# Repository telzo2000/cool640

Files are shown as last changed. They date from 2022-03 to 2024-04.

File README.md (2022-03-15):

# cool640

<br>

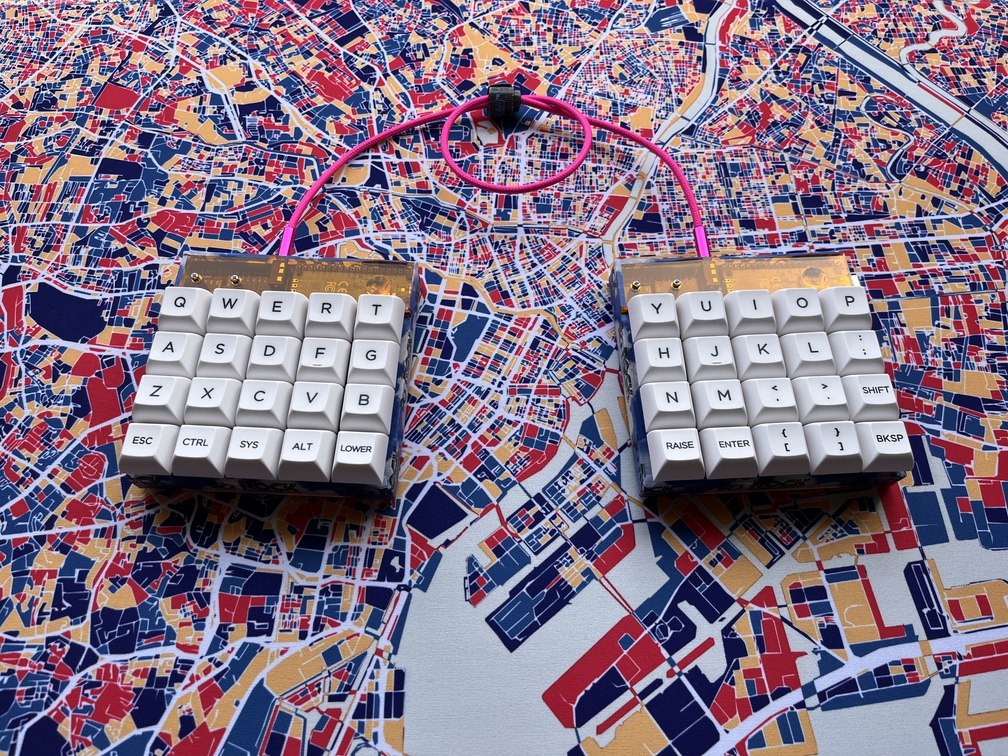
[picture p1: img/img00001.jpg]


## What is cool640？

cool640 is 4X5 macro pad keyboard.
<br>
If you align the two, you will have a split keyboard.
<br><br>
cool640は4X5のマクロパッドキーボードです。
<br>
cool640は二つ揃えると、分割キーボードになります。
<br><br>
You can choose either pro micro or raspberry pi pico to use.
<br><br>
pro microかraspberry pi picoのどちらか一つを選んで使うことができます。

<br><br>
You can choose either choc switch or cherry mx switch to use.
<br>
Chocスイッチか CHERRY MXスイッチのどちらか一つを選んで使うことができます。

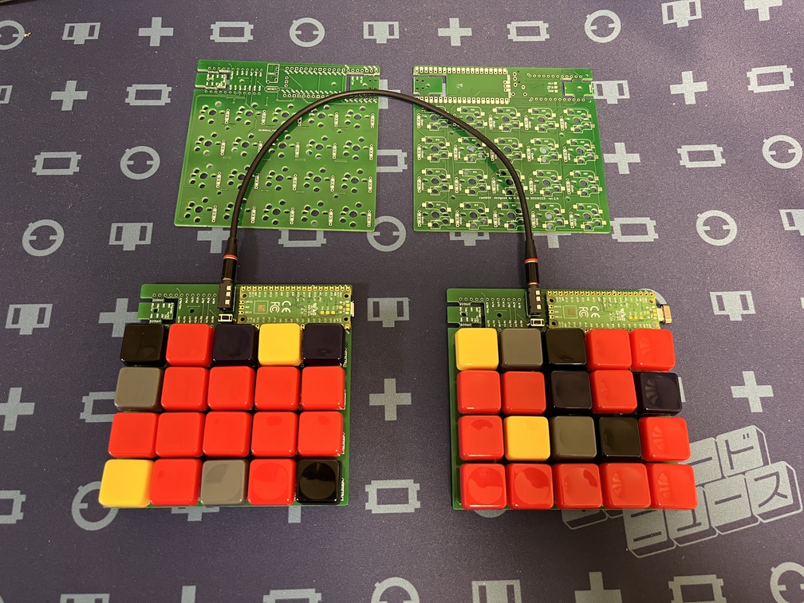
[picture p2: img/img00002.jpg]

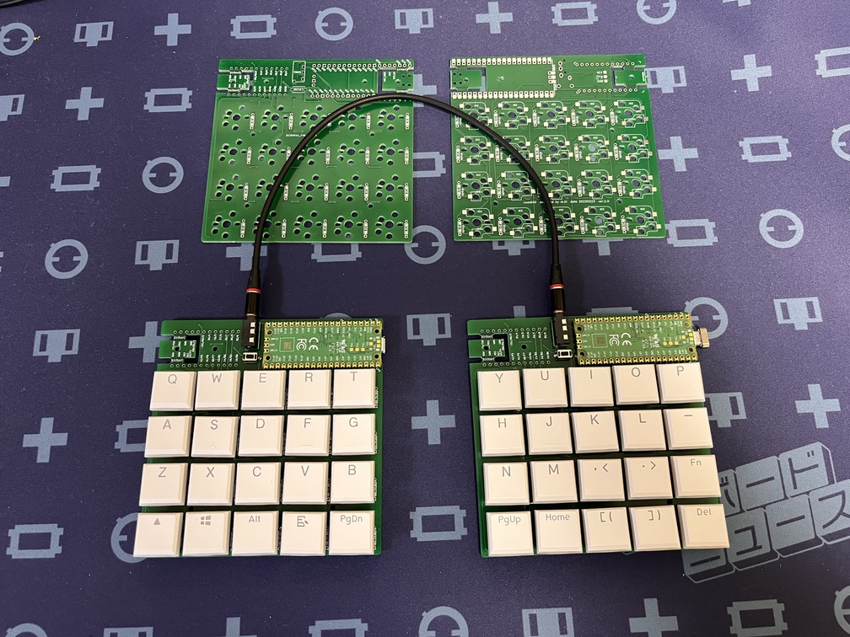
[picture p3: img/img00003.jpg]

<br>
The size of the PCB is within 100mmX100mm.
<br>
It will be distributed on booth in the future, but you can freely use the data here and place an order with the PCB manufacturer.
<br><br>
PCBのサイズは、100mmX100mm以内です。
<br>
将来、boothにて頒布しますが、ここにあるデータを自由に使い、各自がPCB製造元に発注しても構いません。
<br><br>
I do not take any responsibility for the data that you freely use.
<br>
Please use at your own risk.
<br><br>
各自が自由に使ったデータについては、私は一切の責任を負いません。
<br>
自己責任で利用してください。
<br>

## Build Guide
https://github.com/telzo2000/cool640/blob/main/buildguide_for_cool640.md

<br>

## Firmware
https://github.com/telzo2000/cool640/tree/main/firmware

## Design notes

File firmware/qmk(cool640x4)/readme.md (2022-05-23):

# cool640x2

cool640x2

*A short description of the keyboard/project*

* Keyboard Maintainer: [m.ki](https://github.com/telzo2000)
* Hardware Supported: *The PCBs, controllers supported*
* Hardware Availability: *Links to where you can find this hardware*

Make example for this keyboard (after setting up your build environment):

    make cool640x2:default

Flashing example for this keyboard:

    make cool640x2:default:flash

See the [build environment setup](https://docs.qmk.fm/#/getting_started_build_tools) and the [make instructions](https://docs.qmk.fm/#/getting_started_make_guide) for more information. Brand new to QMK? Start with our [Complete Newbs Guide](https://docs.qmk.fm/#/newbs).

## Bootloader

Enter the bootloader in 3 ways:

* **Bootmagic reset**: Hold down the key at (0,0) in the matrix (usually the top left key or Escape) and plug in the keyboard
* **Physical reset button**: Briefly press the button on the back of the PCB - some may have pads you must short instead
* **Keycode in layout**: Press the key mapped to `RESET` if it is available

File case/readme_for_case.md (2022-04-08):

The size of the acrylic board is listed at the end of the file name.
<br>
ファイル名の末尾にアクリル板のサイズが記載してあります。
<br>
The thickness of acrylic is 2mm.
<br>
アクリルの厚みは、２mmです。
<br>
<br>
ボトムプレートを自作する場合、
<br>
横が98.24mm、縦が99.47mmで設計されているので、
<br>
ほぼ、100mm四方のアクリルを使って、必要な箇所にネジ穴（直径2mm程度）を作れば、PCBからM2ネジを挿しこみ、スペーサー等を使って、ボトムプレート固定することができます。
<br>

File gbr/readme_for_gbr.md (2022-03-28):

The dimensions of the PCB will be 98mmX98mm.
<br>
If you place an order with Elecrow, you will need to change the extension.
<br>
PCBの寸法は98mmX98mmになります。
<br>
Elecrowに発注する場合は、拡張子の変更が必要となります。
<br>
elecrow用に拡張子を変更したものが、elecrowという名のリポジトリ内にあります。

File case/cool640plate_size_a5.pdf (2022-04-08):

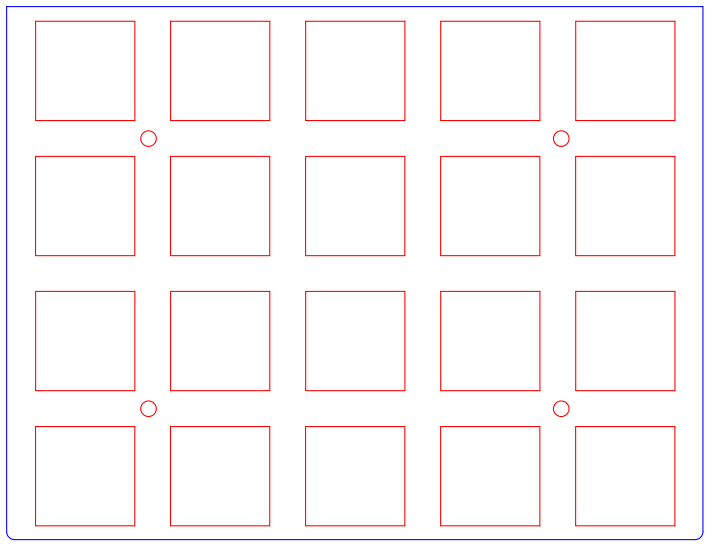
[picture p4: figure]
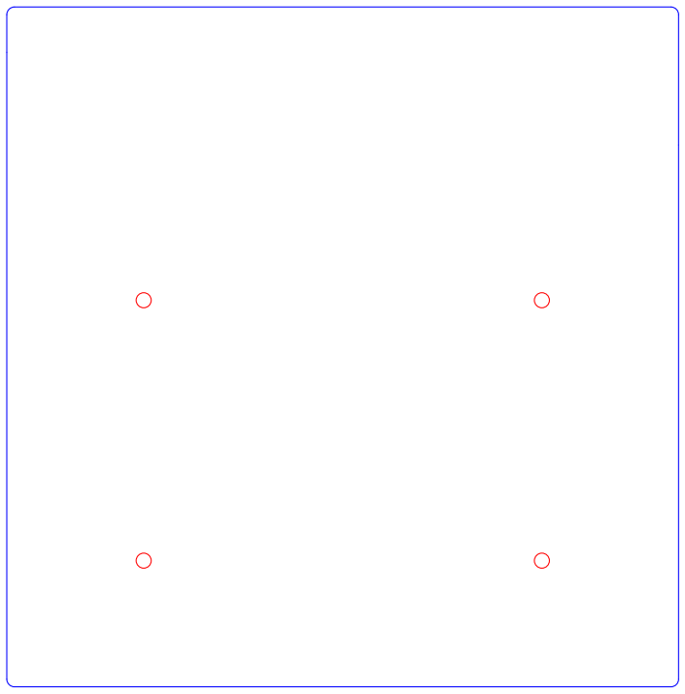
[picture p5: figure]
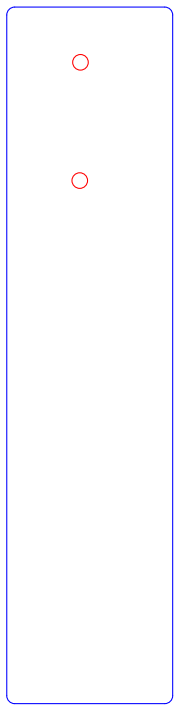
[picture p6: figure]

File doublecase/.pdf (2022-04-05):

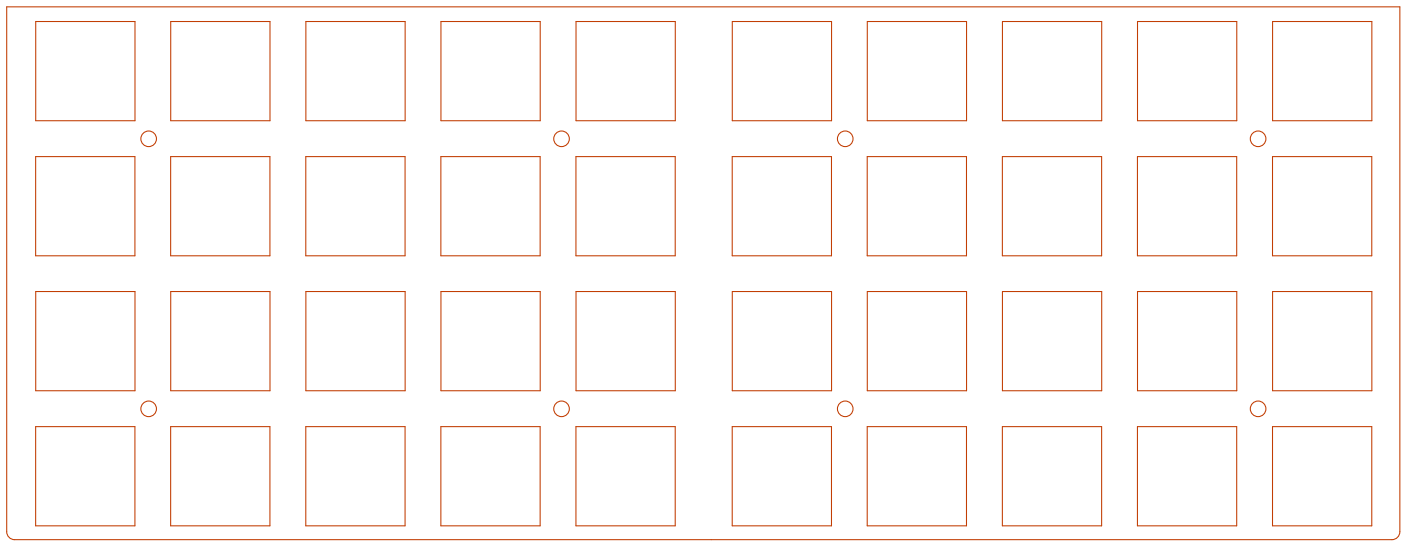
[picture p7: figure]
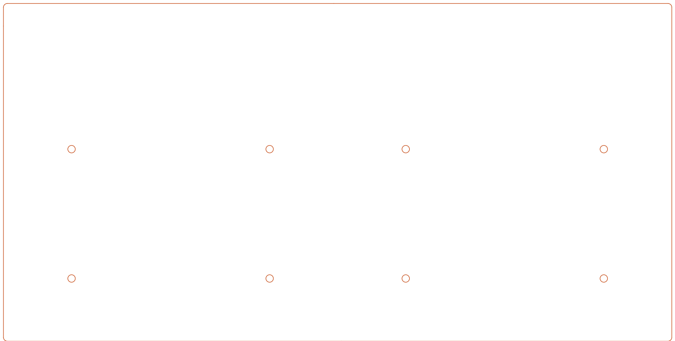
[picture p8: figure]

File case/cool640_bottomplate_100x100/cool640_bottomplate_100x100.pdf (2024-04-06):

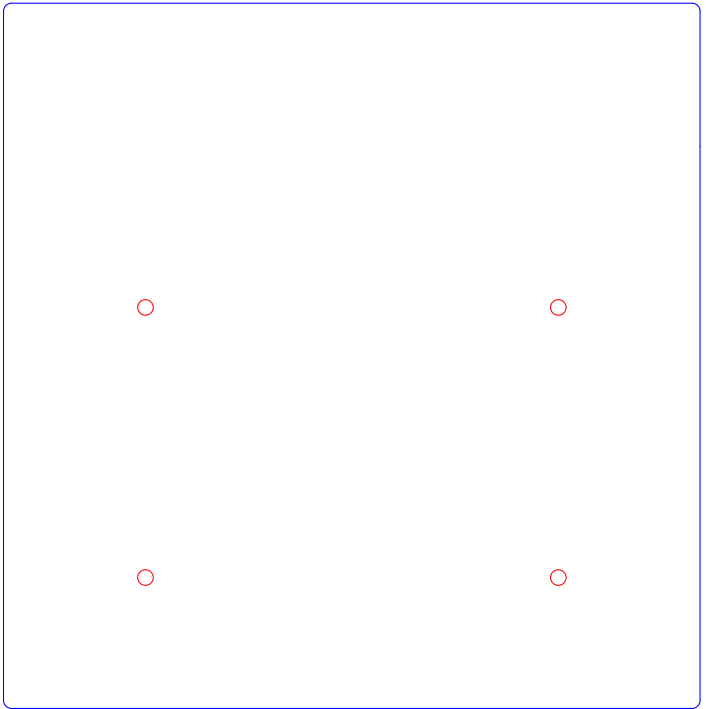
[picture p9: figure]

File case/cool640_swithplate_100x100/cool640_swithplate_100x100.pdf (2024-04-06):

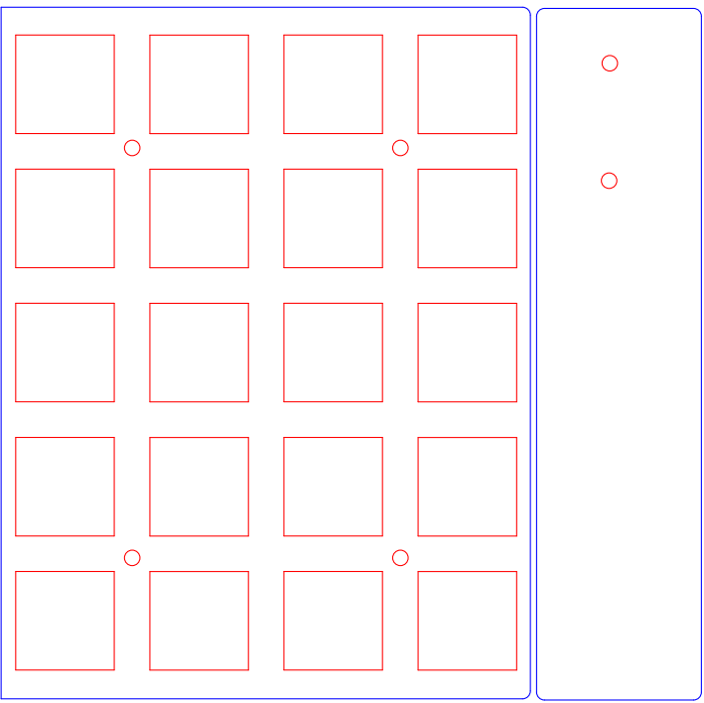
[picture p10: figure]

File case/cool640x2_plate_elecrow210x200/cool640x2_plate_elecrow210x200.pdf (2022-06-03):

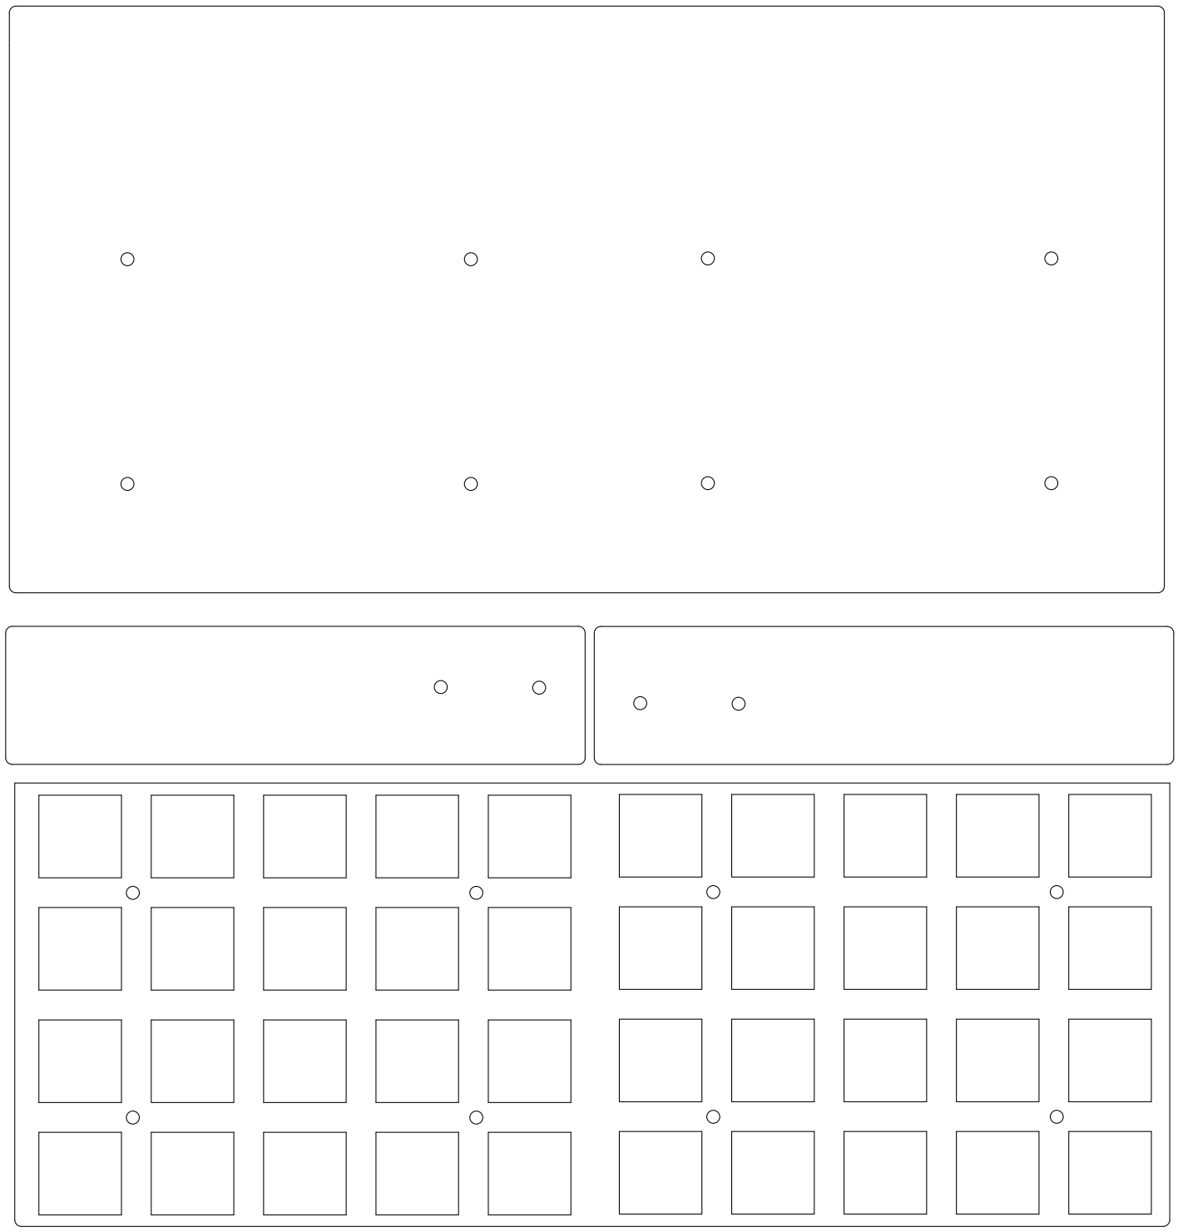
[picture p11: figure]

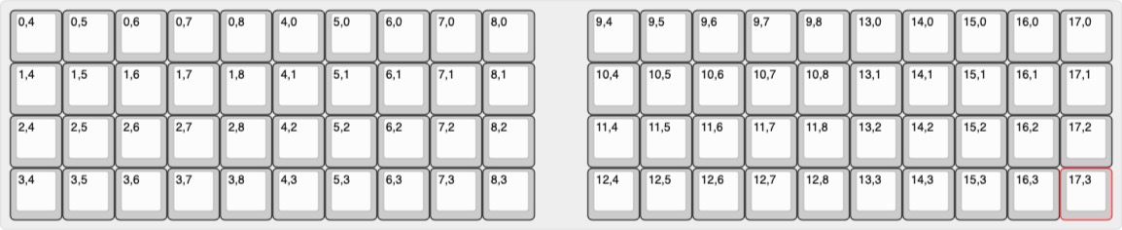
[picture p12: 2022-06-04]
cool640x4_design/cool640x4.jpg

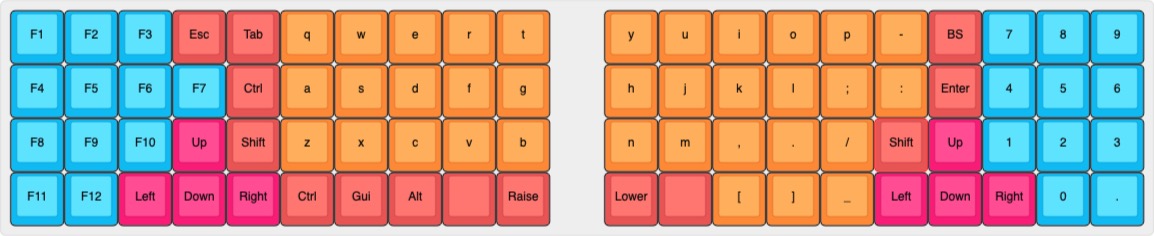
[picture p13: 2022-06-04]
cool640x4_design/cool640x4-2.jpg

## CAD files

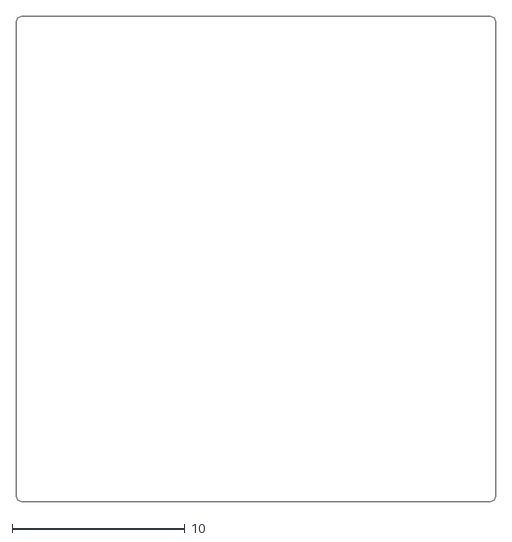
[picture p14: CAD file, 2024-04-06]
case/cool640_bottomplate_100x100/cool640_bottomplate_100x100.dxf
27.7 x 28.1

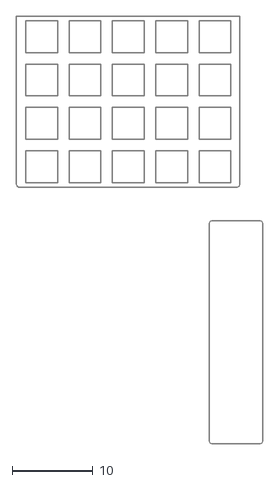
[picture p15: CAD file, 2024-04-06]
case/cool640_swithplate_100x100/cool640_swithplate_100x100.dxf
30.5 x 53.1

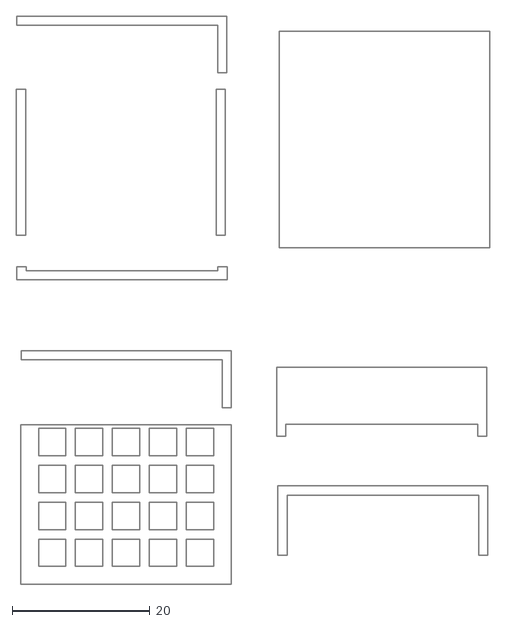
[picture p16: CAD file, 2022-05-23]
case_wide/cool640case_wide.dxf
68.9 x 82.6

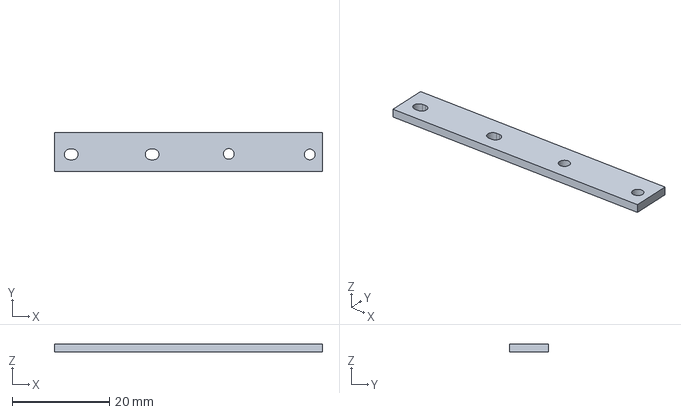
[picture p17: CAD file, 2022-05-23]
kicad_cool640/cool640gattai/cool640gattai.step
55.2 x 7.98 x 1.60 mm

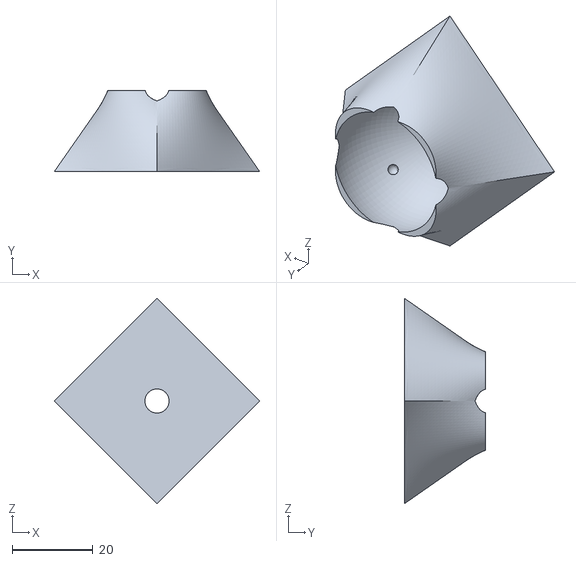
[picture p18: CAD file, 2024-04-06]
case/cool640_swithplate_100x100/trackball_case v2.stl
50.9 x 20.0 x 50.9

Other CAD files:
case/cool640_swithplate_100x100/trackball_case v1.stl

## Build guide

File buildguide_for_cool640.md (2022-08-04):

# Build guide

## Parts list

| No. | Patrs | Quantity | remarks | Suppliers | Cost |
|--|--|--|--|--|--|
|番号|名前|数|備考|調達先|参考価格（送料込）|<br>
|1|PCB|1|4X5Macro pad<br>keyboard|[elecrow](https://www.elecrow.com)<br>[JLCPCB](https://jlcpcb.com)<br>[ALLPCB](https://www.allpcb.com)|５枚で10〜20ドル|<br>
||PCB|2|40%splite keyboard|↑|↑|
|2-1|Switch Plate<br>スイッチプレート|１〜２|Macropadは１枚<br>splite keyboardは２枚|[工房Emerge+](https://www.emergeplus.jp/laser-cutting-service/contact/)<br>[遊舎工房](https://yushakobo.jp)<br>[elecrow](https://www.elecrow.com)|種類による。|
|2-2|Cover Plate<br>カバープレート|１～２|↑|↑|↑|
|2-3|Bottom Plate<br>ボトムプレート|１～２|↑|↑|↑|
|3|M2screw<br>M2ネジ|4X1〜2|4mm<br>CoverPlateで使用|DIYショップなど|10本で100円程度|
|4|M2screw<br>M2ネジ|4X1〜2|3mm|↑|↑|
|5A|M2screw<br>M2ネジ|4X1〜2|8mm<br>MXスイッチ使用時|↑|↑|
|5B|M2screw<br>M2ネジ|4X1〜2|6mm<br>chocスッチ使用時|↑|↑|
|6A|M2spacer<br>M2スペーサー|8X1〜2|3mmメス-メス<br>MXスイッチ使用時|[ヒロスギネット](https://www.hirosugi-net.co.jp/shop/c/c10/)<br>[遊舎工房](https://yushakobo.jp)|20本で800円程度|
|6B|M2spacer<br>M2スペーサー|4X1〜2|3mmメス-メス<br>chocスイッチ使用時|[ヒロスギネット](https://www.hirosugi-net.co.jp/shop/c/c10/)<br>[遊舎工房](https://yushakobo.jp)|20本で800円程度|
|7|M2spacer<br>M2スペーサー|2X1〜2|6mmメス-メス<br>CoverPlateで使用|[ヒロスギネット](https://www.hirosugi-net.co.jp/shop/c/c10/)<br>[遊舎工房](https://yushakobo.jp)|20本で800円程度|
|8|pro micro|1〜2|ピンヘッダも別途購入|[遊舎工房](https://yushakobo.jp)<br>[Talp Keyboard](https://talpkeyboard.net)<br>[Daily Craft Keyboard](https://shop.dailycraft.jp)等|価格変動中|
||Raspberry Pi Pico|1〜2|ピンヘッダも別途購入|[遊舎工房](https://yushakobo.jp)等|１個550円|
|9A|Swith socket<br>スイッチソケット|20X1〜2|cherry MX互換|[遊舎工房](https://yushakobo.jp)<br>[Talp Keyboard](https://talpkeyboard.net)<br>[Daily Craft Keyboard](https://shop.dailycraft.jp)等|10個で165円程度|
|9B|Swith socket<br>スイッチソケット|20X1〜2|choc互換|[遊舎工房](https://yushakobo.jp)<br>[Talp Keyboard](https://talpkeyboard.net)<br>[Daily Craft Keyboard](https://shop.dailycraft.jp)等|10個で165円程度|
|10|Diode<br>ダイオード|20X1〜2|リードタイプでもSMDでも可|[遊舎工房](https://yushakobo.jp)<br>[Talp Keyboard](https://talpkeyboard.net)<br>[Daily Craft Keyboard](https://shop.dailycraft.jp)等|100個で220円程度から|
|11|タクトスイッチ|1〜2|２本足のもの|[遊舎工房](https://yushakobo.jp)<br>[Talp Keyboard](https://talpkeyboard.net)<br>[Daily Craft Keyboard](https://shop.dailycraft.jp)等|１個11円程度|
|12|TRRSジャック|1〜2|MJ-4PP-9|[遊舎工房](https://yushakobo.jp)<br>[Talp Keyboard](https://talpkeyboard.net)<br>[Daily Craft Keyboard](https://shop.dailycraft.jp)等|１個55円|

この他に、TRRSケーブル、USBケーブル、キーキャップ等が必要です。

## Firmware

### 1 PRK_FIRMWARE

[Here](https://github.com/telzo2000/cool640/tree/main/firmware)

<br>
For those who are introducing PRK for the first time.
<br>
初めてのPRKを導入する方に
<br>
Only Japanese tweets.
<br>
日本語ツイートのみです。
<br>

https://twitter.com/0002ozlet/status/1512535045957111810

### 2 QMK_FIRMWARE
[Here](https://github.com/telzo2000/cool640/tree/main/firmware)

<br>

## Build 1(PCB only)

### 1 Parts check

Front side（表面）

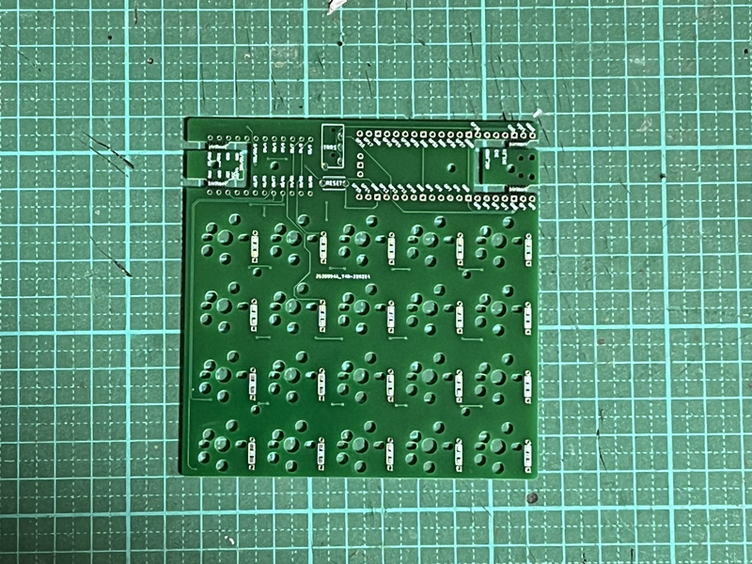
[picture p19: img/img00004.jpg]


Back side（裏面）

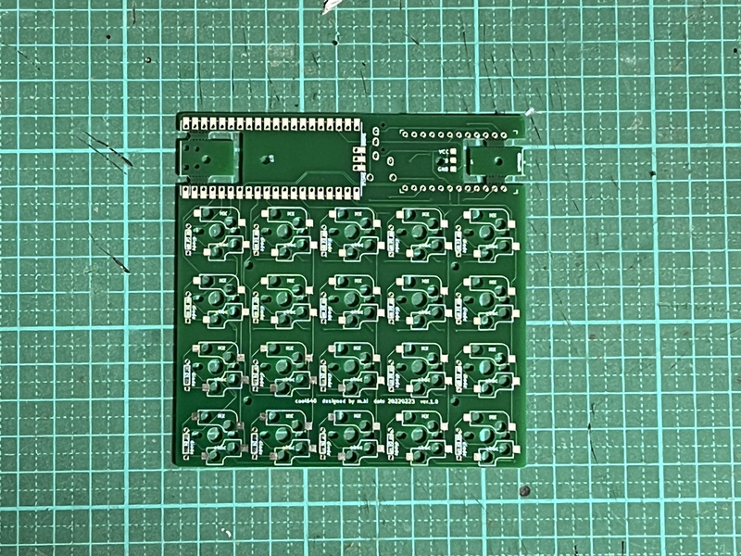
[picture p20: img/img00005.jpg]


### 2 Diode soldering

Solder the diode on the back side.
<br>
裏面にダイオードのハンダ付けをします。
<br>

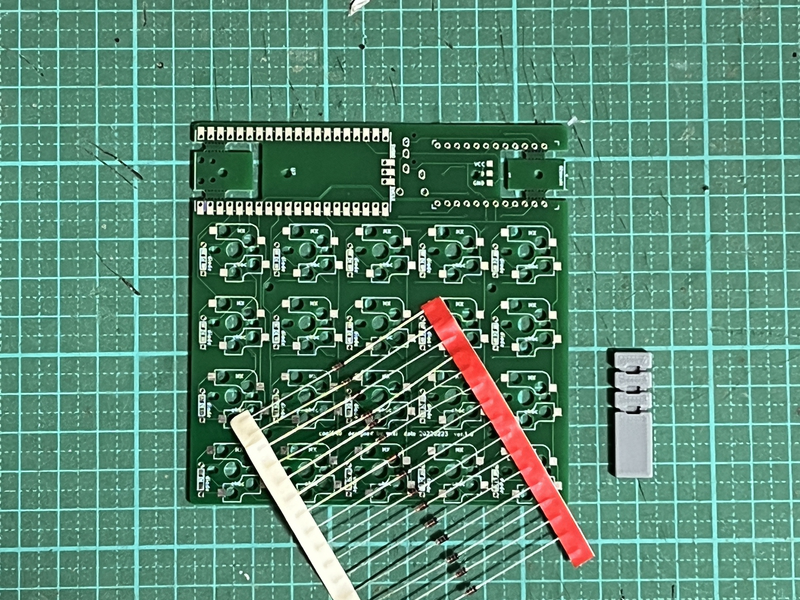
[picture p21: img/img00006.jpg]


There are lead type and SMD diodes.
<br>
ダイオードはリードタイプか、SMDがあります。
<br>
Here, we will explain the lead type soldering.
<br>
ここでは、リードタイプのハンダ付けの説明をします。
<br>
However, those who adopt the choc switch should use SMD diodes.
<br>
ただし、chocスイッチを採用する人は、SMDのダイオードを使用してください。
<br>

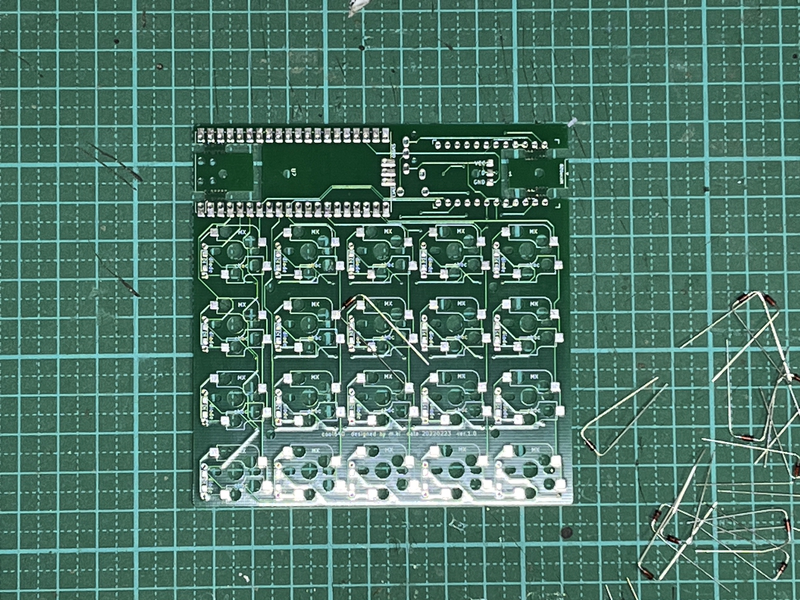
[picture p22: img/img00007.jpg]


Use a lead bender to bend the legs of the diode.
<br>
リードベンダーを使い、ダイオードの足を曲げます。
<br>

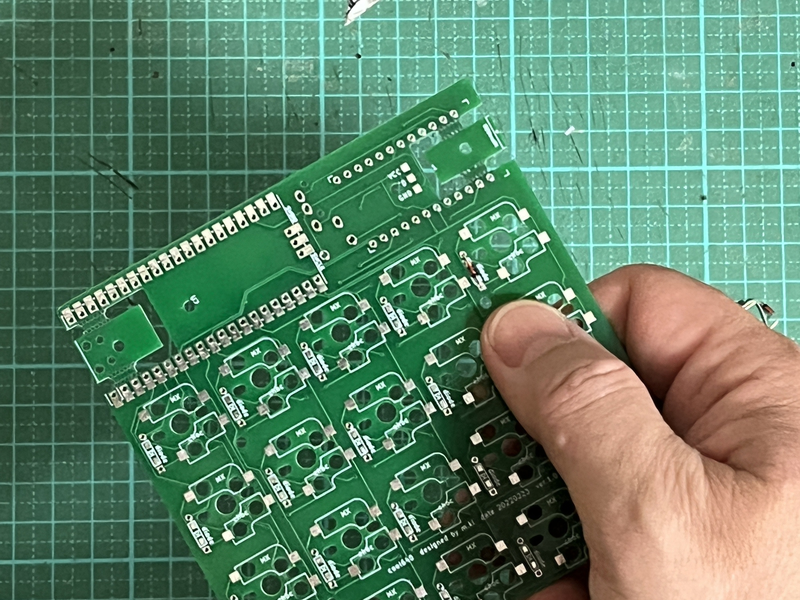
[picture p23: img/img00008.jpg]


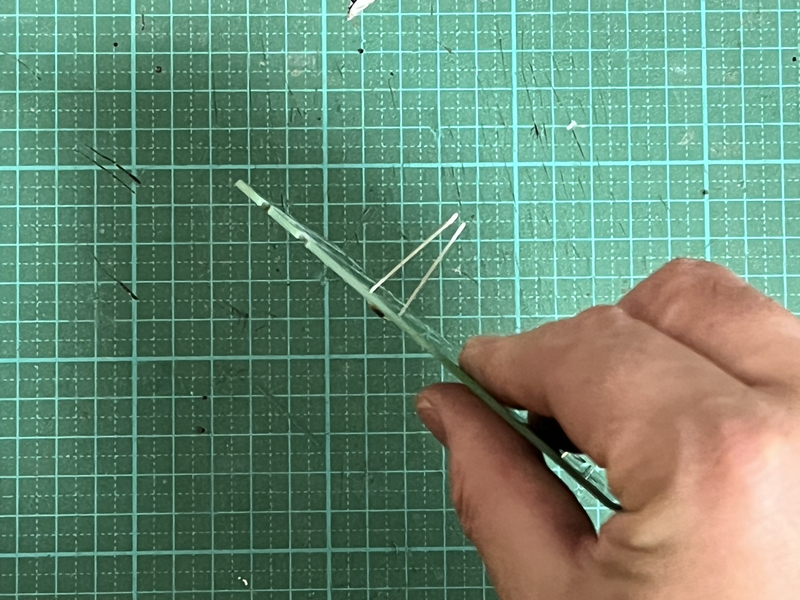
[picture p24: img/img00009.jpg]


Insert the diode into the board.
<br>
ダイオードを基板に挿しこみます。
<br>

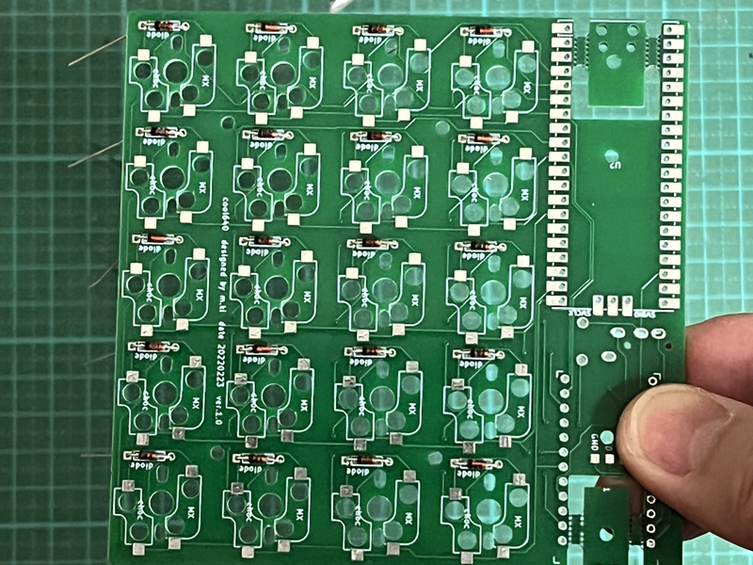
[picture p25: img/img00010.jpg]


Please refer to the image and pay attention to the orientation of the diode.
<br>
画像を参考にして、ダイオードの向きに注意してください。
<br>

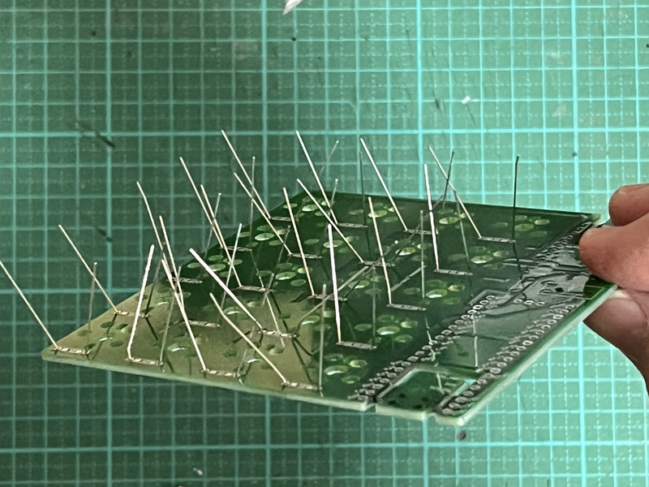
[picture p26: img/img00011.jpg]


Secure the diode with masking tape, then face up.
<br>
マスキングテープでダイオードを固定してから、表面を上にします。
<br>
Solder the protruding legs.
<br>
はみ出ている足部分に、ハンダ付けをします。
<br>
After soldering, use nippers to cut off the protruding legs.
<br>
はんだ付けが終わったら、はみ出ている足をニッパーで切り取ってください。
<br>

[８倍速　Diodeハンダ付け動画](https://youtu.be/Yaodh2-XxV4)

<br>
<br>

### 3 Soldering switch sockets

Solder the switch sockets on the back side.
<br>
裏面にスイッチソケットのハンダ付けをします。
<br>
cool640 is compatible with both choc and cherry MX switches.
<br>
cool640はchocスイッチとcherryMXスイッチの両方に対応しています。
<br>
Both can be installed.
<br>
両方を取り付けることが可能です。
<br>
Here, solder the cherryMX switch.
<br>
ここでは、cherryMXスイッチのハンダ付けを行います。
<br>
Place the switch socket so that the letters MX are hidden.
<br>
MXという文字が隠れるように、スイッチソケットを乗せてください。
<br>
That is the correct switch socket orientation.
<br>
それが正しいスイッチソケットの向きになります。
<br>
When using a choc switch, place the switch socket so that the letters choc are hidden.
<br>
chocスイッチの時は、chocという文字が隠れるように、スイッチソケットを乗せてください。
<br>

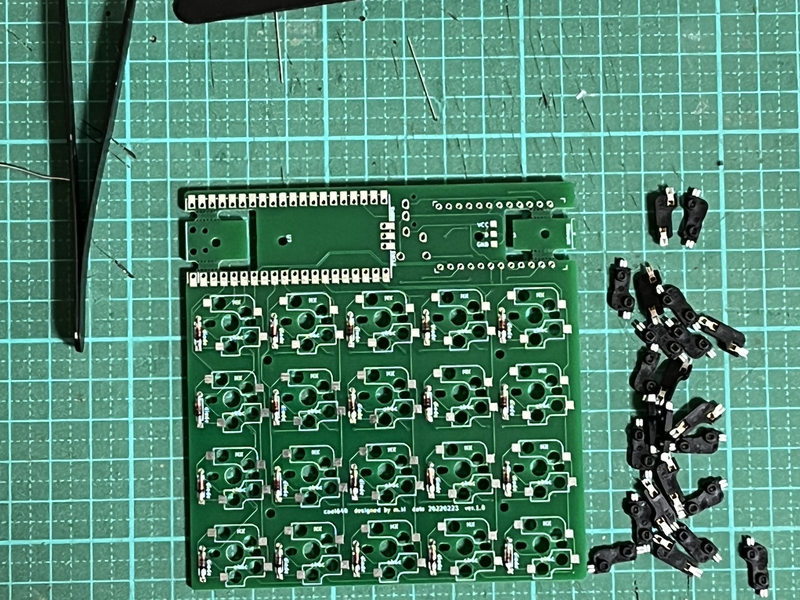
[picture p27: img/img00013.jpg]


Apply solder to both pads.
<br>
両方のパッドにハンダを盛ります。
<br>
Place the switch socket and fix it with a warm soldering iron while melting the solder.
<br>
スイッチソケットを乗せて、温めたハンダゴテで、ハンダを溶かしながら、固定します。
<br>
You can make it easier by working while holding it with tweezers.
<br>
ピンセットで押さえながら、作業をすると楽にできます。
<br>

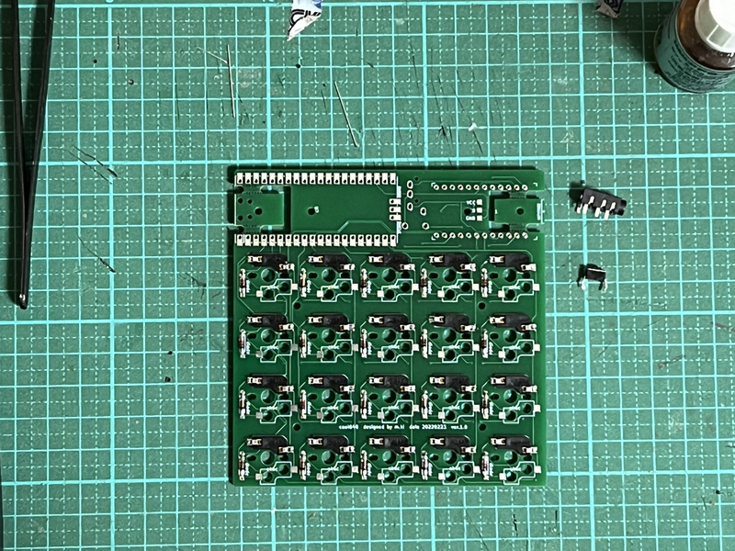
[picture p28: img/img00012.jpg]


[８倍速　Switch socketハンダ付け動画](https://youtu.be/E__mHvmIXQo)

<br><br>

### 4 Soldering reset switch & TRRS jack 

Insert the reset switch on the surface.
<br>
表面にリセットスイッチを挿しこみます。
<br>
Solder the legs of the reset switch from the back.
<br>
裏面からリセットスイッチの足をハンダ付けします。
<br>
Solder the TRRS jack in the same way near the reset switch.
<br>
TRRSジャックは、リセットスイッチの近くに同じようにハンダ付けします。

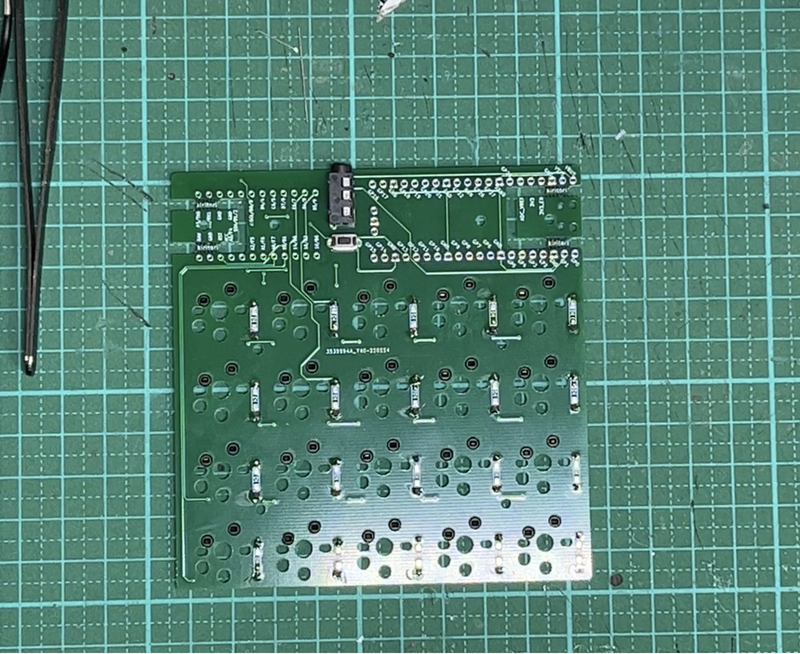
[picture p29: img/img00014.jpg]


[８倍速　Reset switch,TRRS jackハンダ付け動画](https://youtu.be/3gEbExaOAv4)

<br><br>

### 5　Choice of Pro micro or Raspberry Pi Pico

You can run cool640 in either Pro micro or Raspberry Pi Pico.
<br>
cool640をpro microかラズパイピコのどちらか一方で動作させることができます。
<br>
＜case 1＞
<br>
When you choose Pro micro, place it on the left side of the TRRS jack.
<br>
pro microを選んだ時、TRRSジャックの左側にpro microを取り付けてください。
<br>

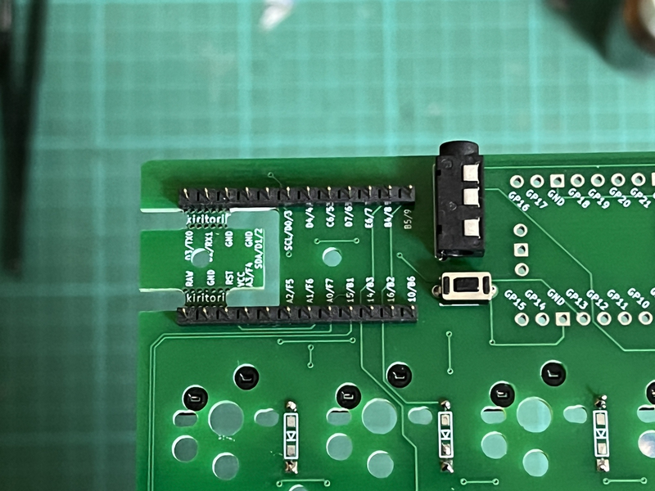
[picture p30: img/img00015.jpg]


Use the conthrough to fix the pro micro with the side with the parts facing down.
<br>
pro microの部品のある面を下向きに、コンスルーを使い、固定してください。
<br>

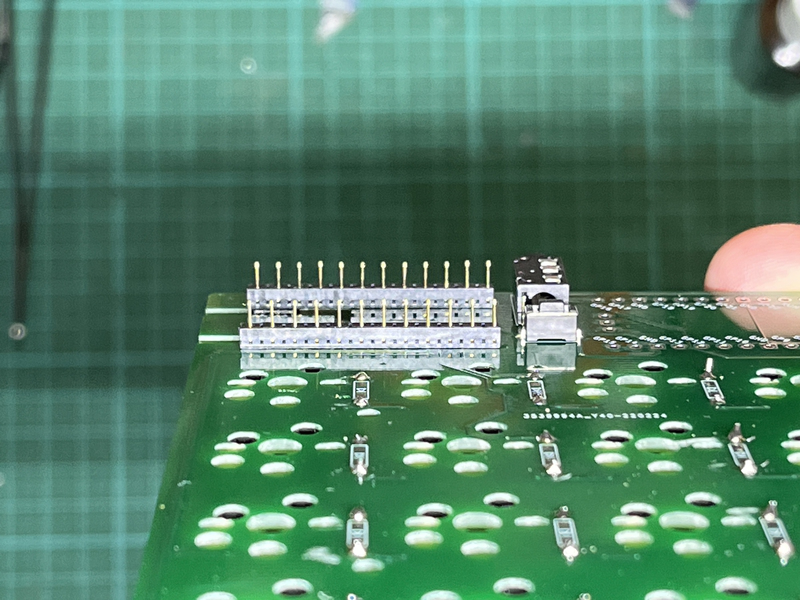
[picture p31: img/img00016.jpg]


Pay attention to the orientation of the conthrough.
<br>
コンスルーの向きに注意してください。
<br>

If the USB port touches the PCB, cut off the part on the left side of the PCB.
<br>
もし、USB端子がPCBに接触するならば、PCBの左側の一部を切りとってください。
<br>

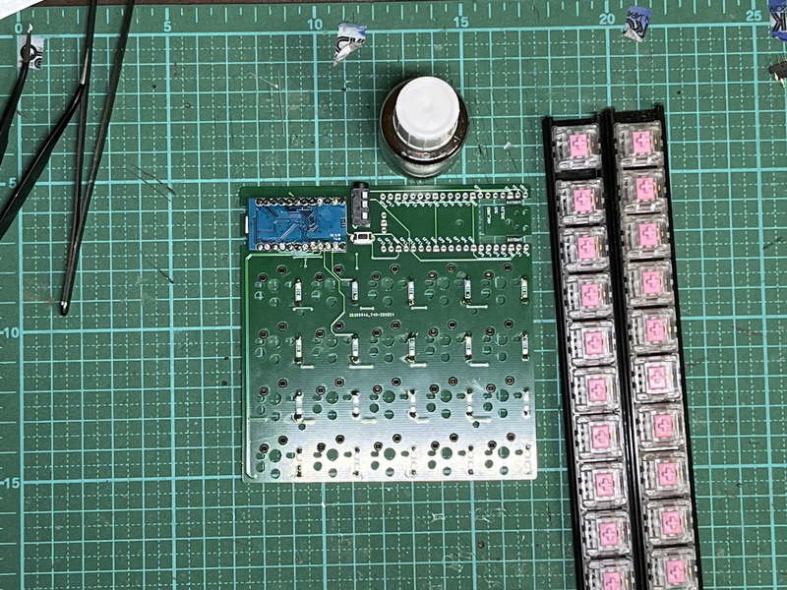
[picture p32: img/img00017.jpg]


＜case 2＞
<br>
When you choose Raspberry Pi Pico, place it on the right side of the TRRS jack.
<br>
ラズパイピコを選んだ時、TRRSジャックの右側にラズパイピコを取り付けてください。

Use the conthrough to fix the Raspberry Pi Pico with the side with the parts facing down.
<br>
ラズパイピコの部品のある面を下向きに、コンスルーを使い、固定してください。
<br>

Pay attention to the orientation of the conthrough.
<br>
コンスルーの向きに注意してください。
<br>

If the USB port touches the PCB, cut off the part on the right side of the PCB.
<br>
もし、USB端子がPCBに接触するならば、PCBの右側の一部を切りとってください。
<br>

<br>

### 6　Test

Please write the firmware and check the operation.
<br>
ファームウェアを書き込んで、動作確認をしてください。
<br>

Install a switch or measure continuity with tweezers, etc.
<br>
スイッチを取り付けるか、ピンセット等で導通をはかるかを行います。
<br>

### PRK_FIRMWARE

[Here](https://github.com/telzo2000/cool640/tree/main/firmware)

<br>

### QMK_FIRMWARE
[Here](https://github.com/telzo2000/cool640/tree/main/firmware)

<br>
<br>

### 7 Installation of key switch

Attach your favorite key switch.
<br>
好きなキースイッチを取り付けてください。
<br>

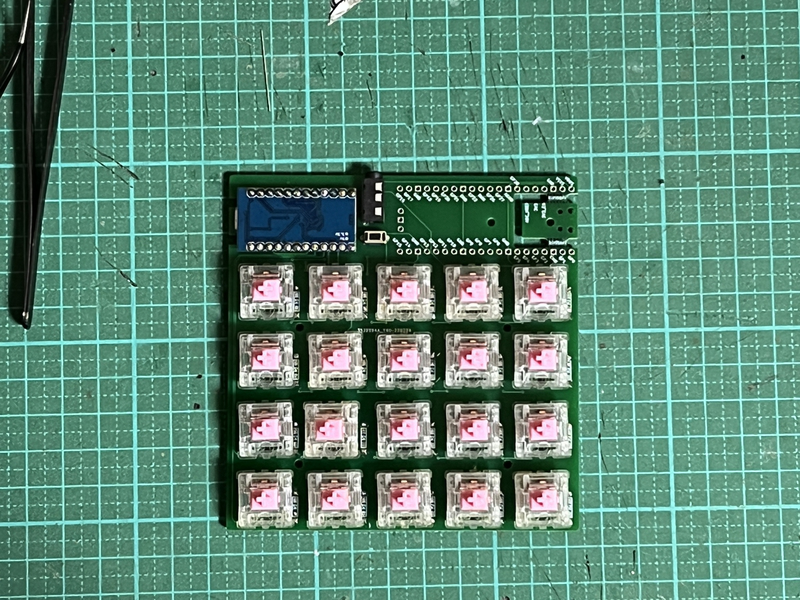
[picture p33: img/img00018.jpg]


<br>
<br>

### 8 Installation of key cap

Attach your favorite key cap.
<br>
好きなキーキャップを取り付けてください。
<br>

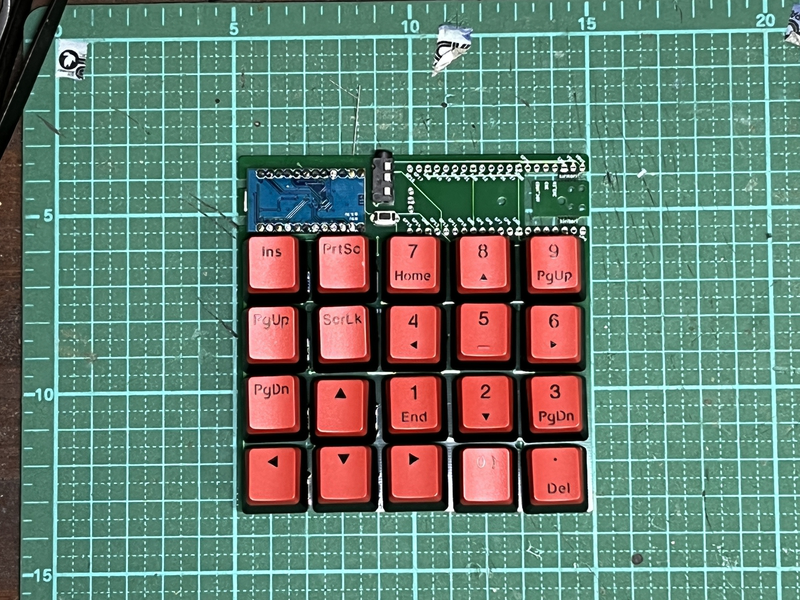
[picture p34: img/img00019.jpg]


<br>
If you like, attach a rubber cushion to the back and you're done.
<br>
お好みで裏面にラバークッションを取り付けたら、完成です。
<br>
<br>
<br>

## Build 2(Acrylic sandwich mount case)

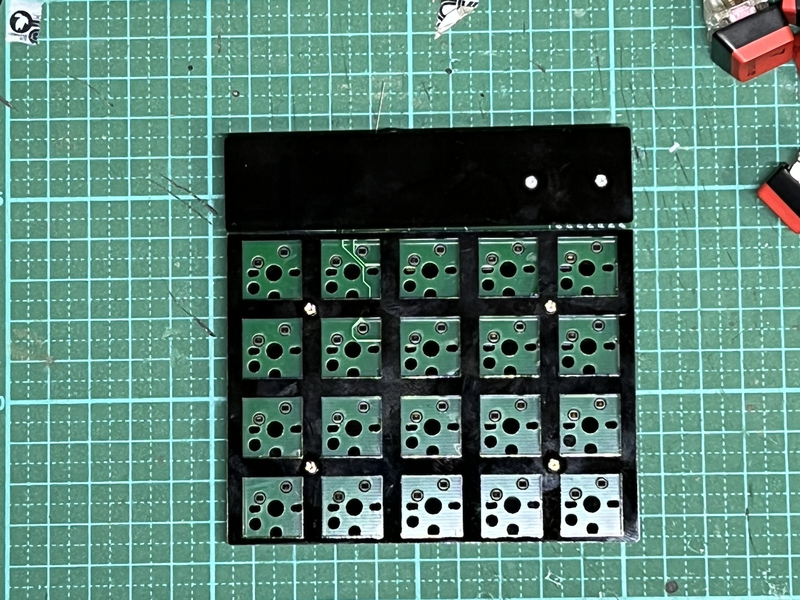
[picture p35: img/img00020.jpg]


After 1 ~ 6 of build1, please do the next step.
<br>
build1の1~6の後、次の工程をしてください。
<br>

### 1 Installation of cover plate

Prepare a cover plate, M2 spacer 6mm（x２）, and M2 screw 3mm（x４）.
<br>
カバープレート、M2スペーサー6mm（２個）、M2ネジ3mm（４本）を用意します。
<br>
Screw the spacer to the cover plate in the same orientation.
<br>
カバープレートに同じ向きで、スペーサーをネジで固定します。
<br>
Then use the remaining screws to attach the cover plate to the PCB.
<br>
次に、残りのネジを使い、カバープレートをPCBに取り付けます。
<br>
There is an orientation of the cover plate, so it is good to check it once before starting work.
<br>
カバープレートの向きがあり、作業前に一度、重ねて確認すると良いです。
<br>
<br>

### 2-1 Installation of switch plate（choc switch）

Prepare a switch plate, M2 spacer 3 mm（x４）, and M2 screw 6 mm（x４）.
<br>
スイッチプレート、M2スペーサー３mm（４本）、M2ネジ６mm（４本）を用意します。
<br>
Fix the screws in 4 places.
<br>
ネジを４箇所、固定します。
<br>
Insert the screws in the order of the switch plate and the PCB, and fix them with spacers on the back of the PCB.
<br>
ネジはスイッチプレート、PCBの順でさしこみ、PCBの裏面でスペーサーで固定します。
<br>

<br>

### 2-2 Installation of switch plate（cherry MX switch）

Prepare a switch plate, M2 spacer 3 mm（x８）, and M2 screw 8 mm（x４）.
<br>
スイッチプレート、M2スペーサー３mm（８本）、M2ネジ８mm（４本）を用意します。
<br>
Fix the screws in 4 places.
<br>
ネジを４箇所、固定します。
<br>
Insert the switch plate into the screw and fix it with a spacer.
<br>
ネジはスイッチプレートをさしこみ、スペーサーで固定します。
<br>
Next, insert the switch plate into the PCB and secure it with a spacer on the back of the PCB.
<br>
次に、スイッチプレートをPCBにさしこみ、PCBの裏面でスペーサーで固定します。
<br>

### 3 Installation of bottom plate 

Prepare the bottom plate and M2 ３mm screws（x４）.
<br>
ボトムプレート、M２ネジ３mm（４本）を用意します。
<br>
Place the bottom plate according to the spacer on the back of the PCB and fix it with screws.
<br>
PCB裏面にあるスペーサーに合わせて、ボトムプレートをのせて、ネジで固定します。
<br>
<br>
From here, proceed with step 7 of build1.
<br>
ここからは、build１の７の工程を進めてください。
<br>

Right:Raspberry Pi Pico & choc switch
<br>
Left :Pro micro & cherry MX switch

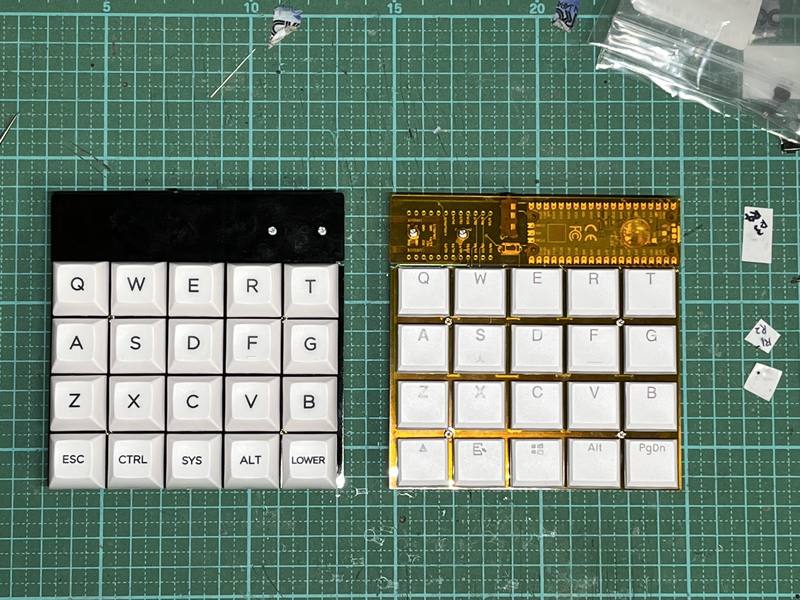
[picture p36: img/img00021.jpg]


From the side

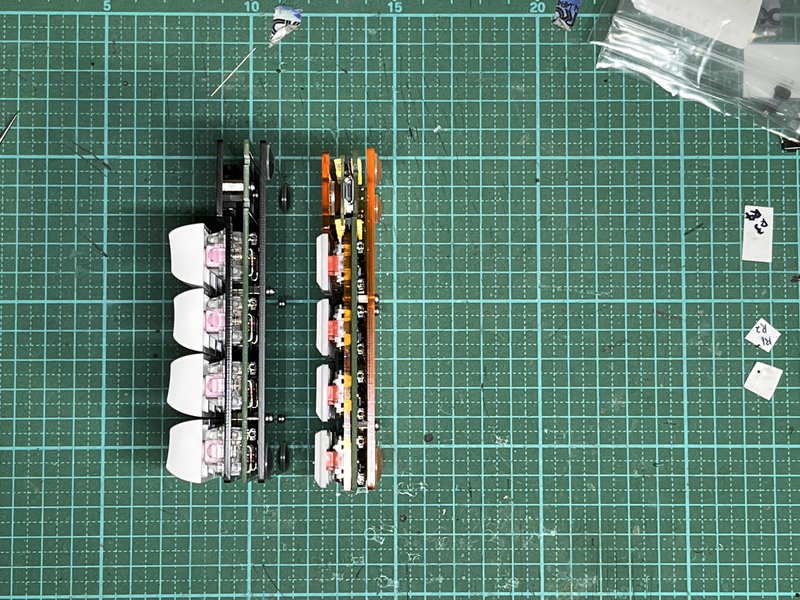
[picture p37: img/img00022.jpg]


<br>

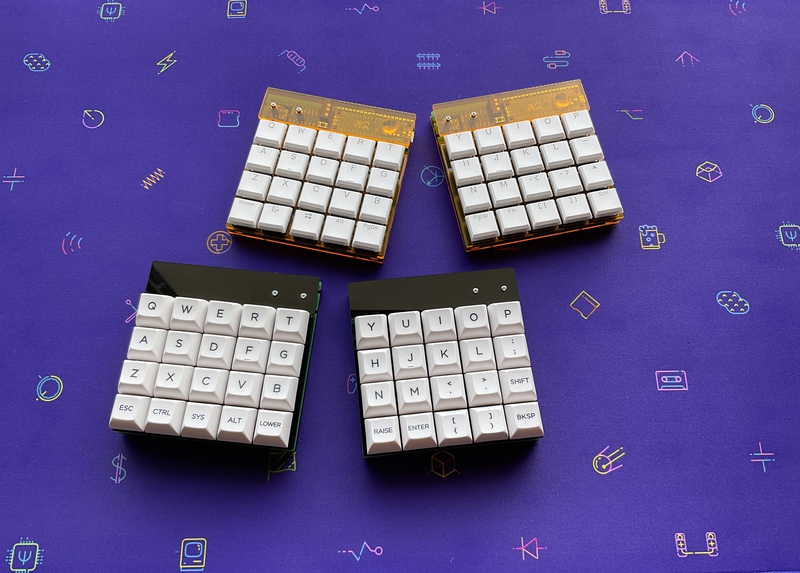
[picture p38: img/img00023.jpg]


Have a fun selfmade keyboard life!
<br>
楽しい自作キーボード生活を!

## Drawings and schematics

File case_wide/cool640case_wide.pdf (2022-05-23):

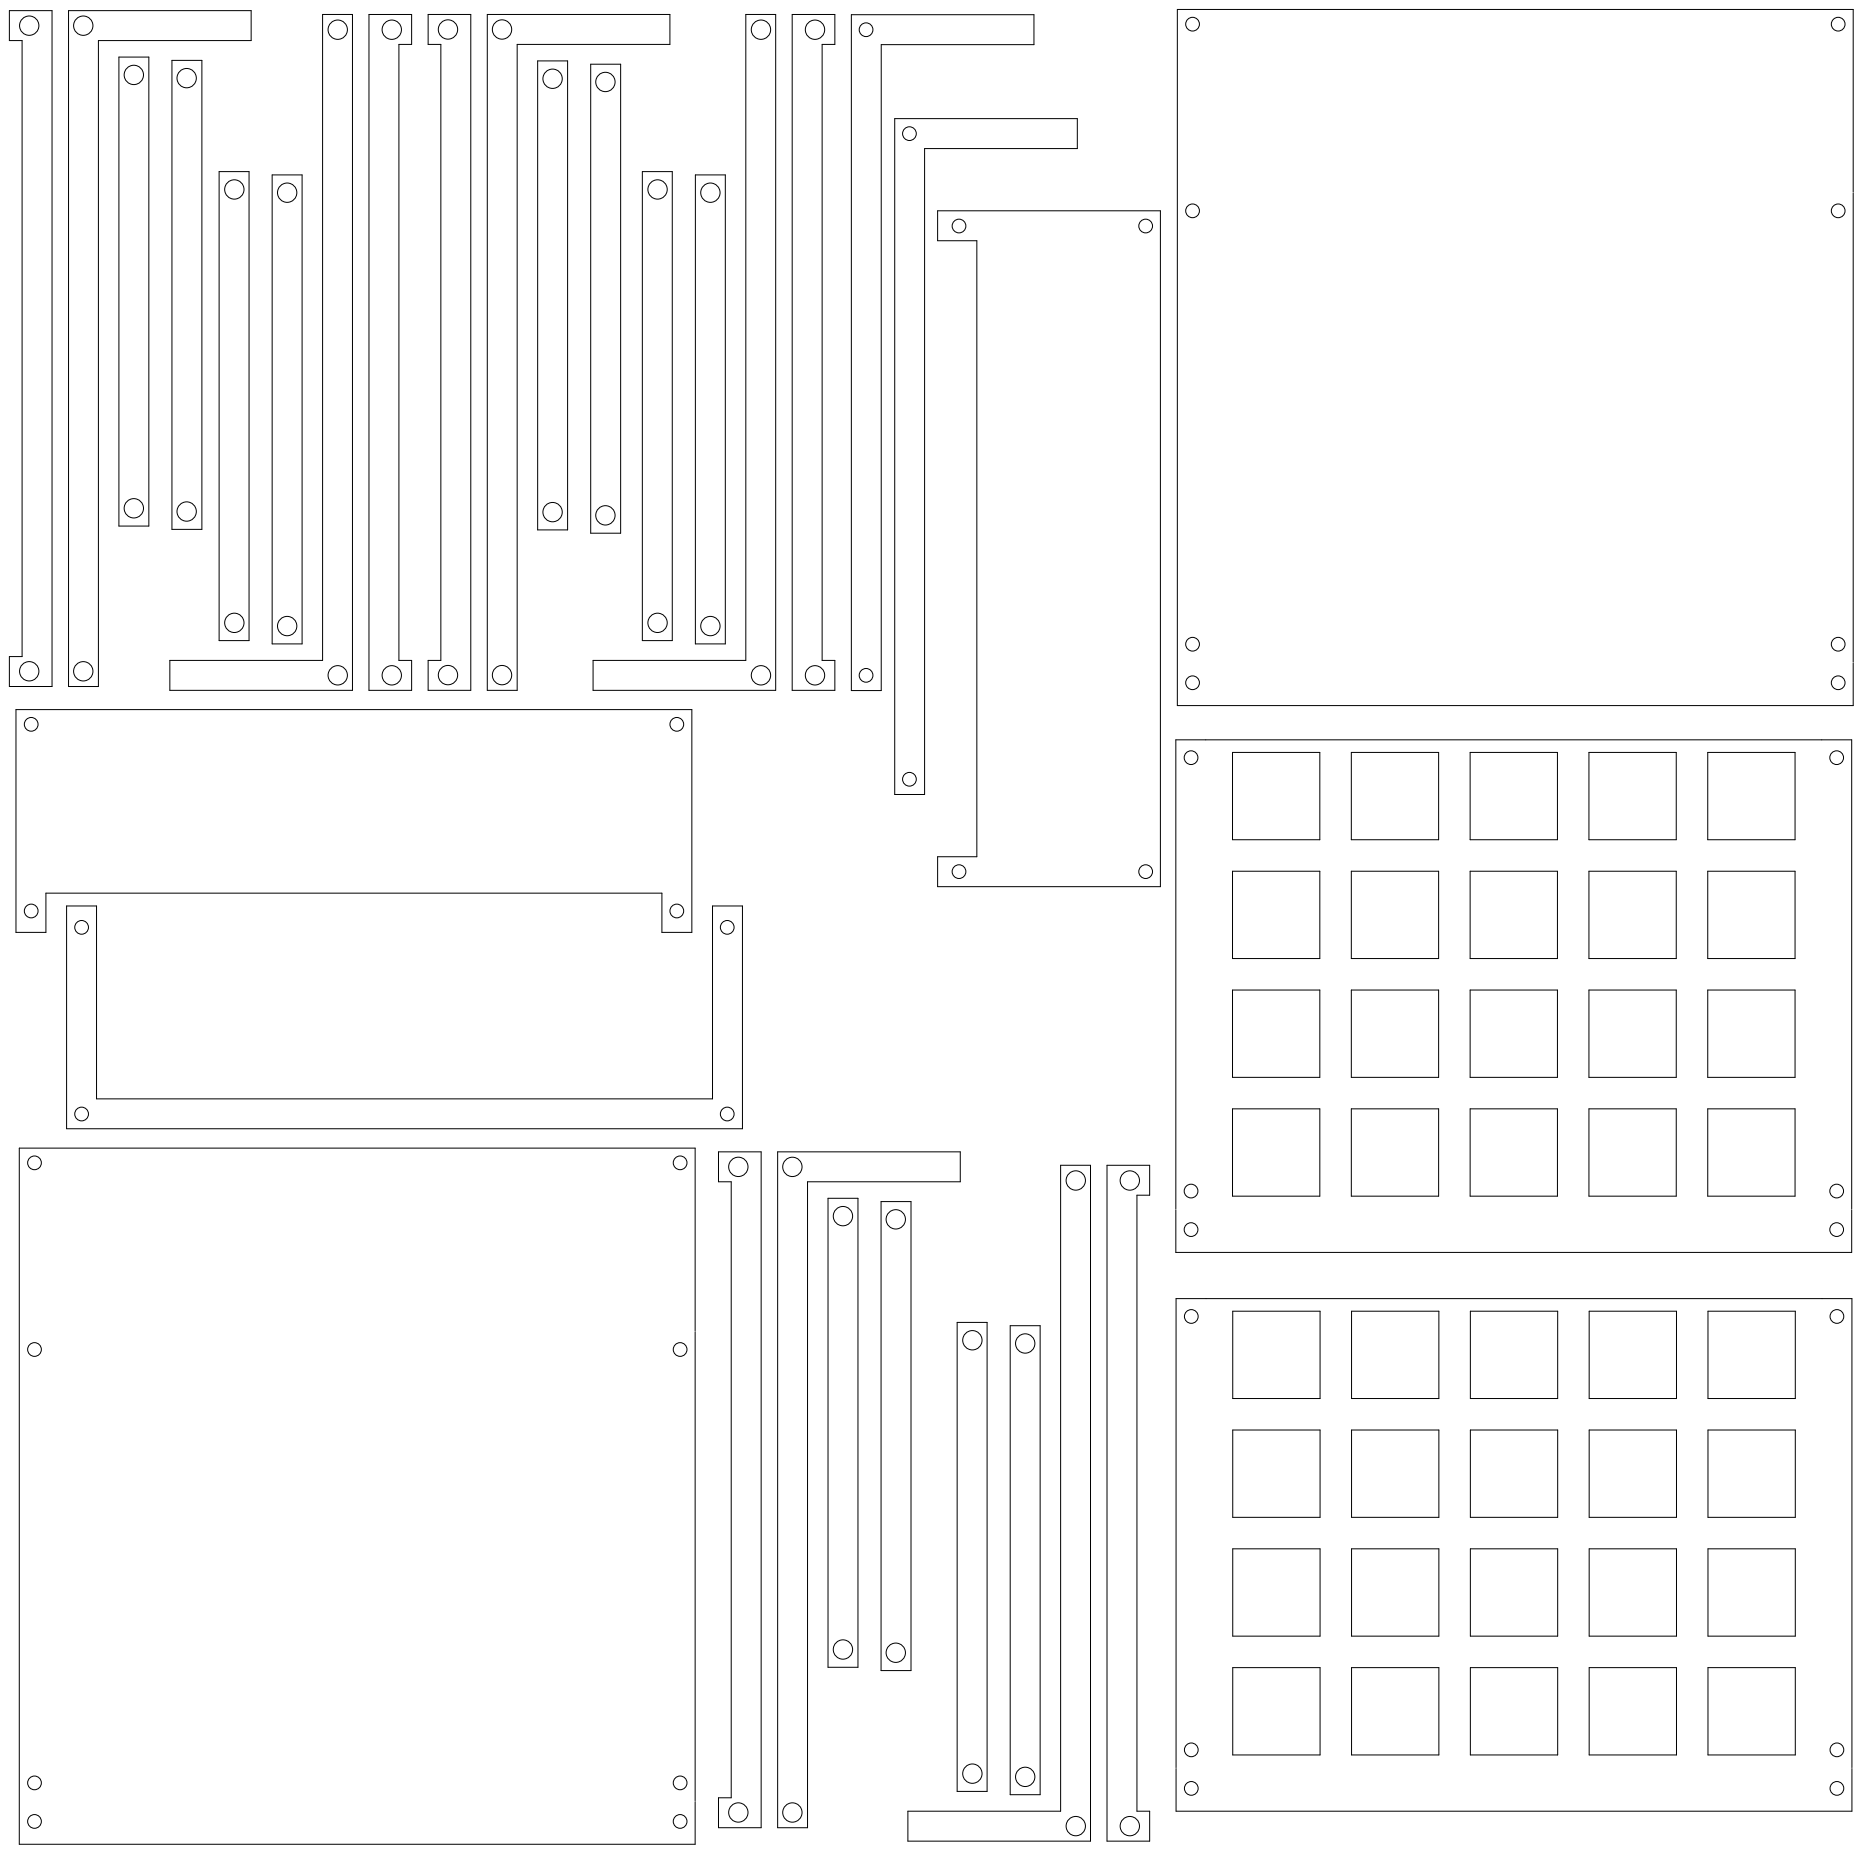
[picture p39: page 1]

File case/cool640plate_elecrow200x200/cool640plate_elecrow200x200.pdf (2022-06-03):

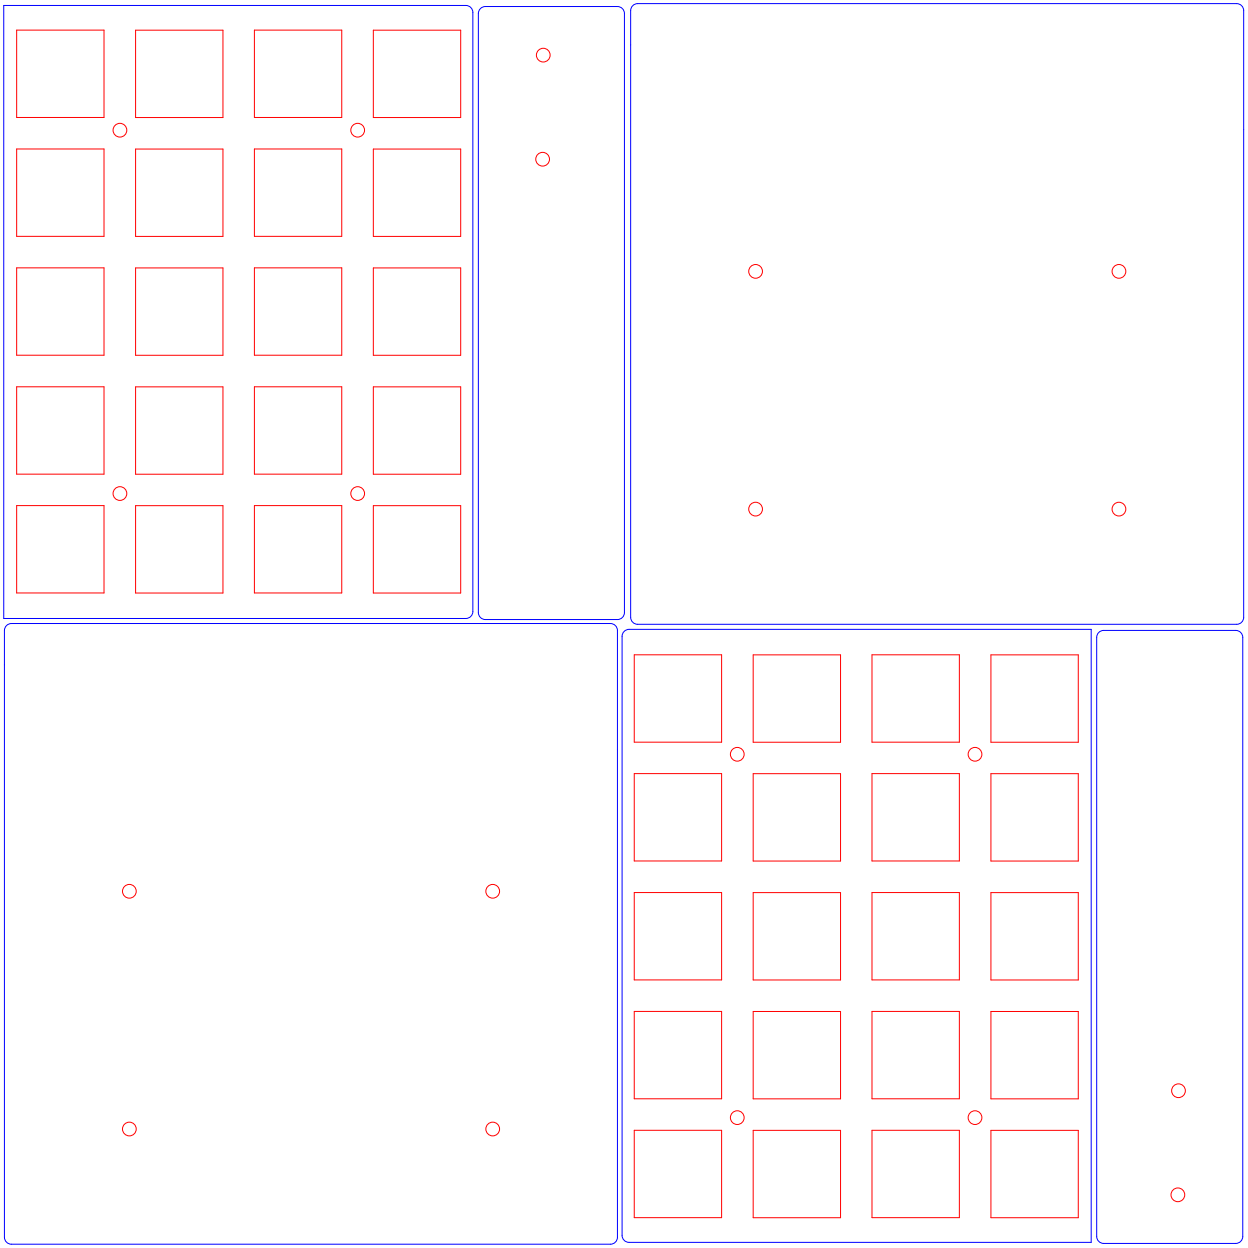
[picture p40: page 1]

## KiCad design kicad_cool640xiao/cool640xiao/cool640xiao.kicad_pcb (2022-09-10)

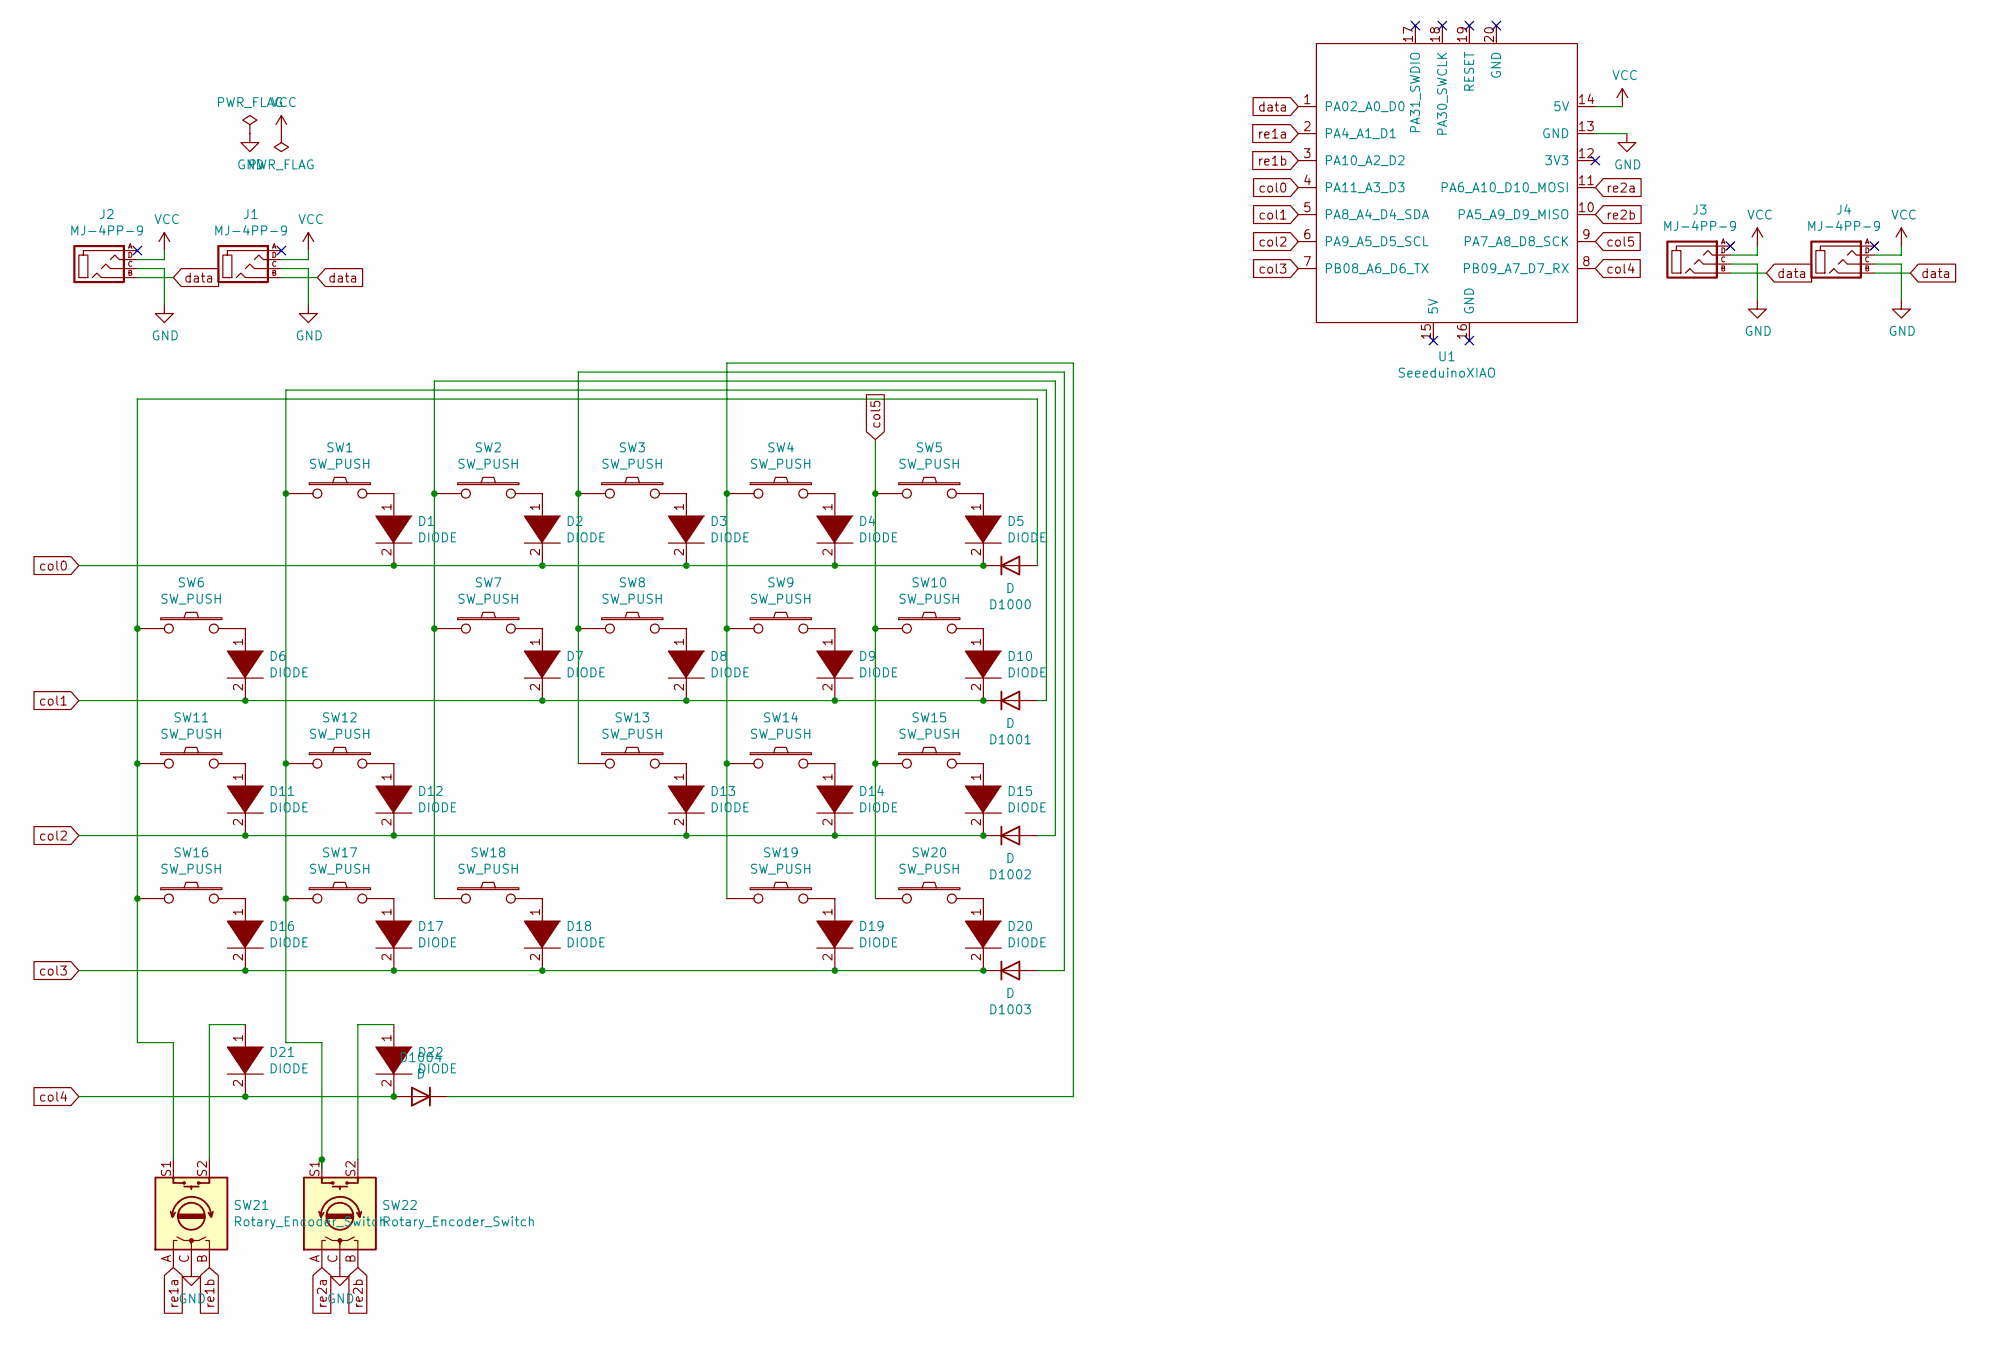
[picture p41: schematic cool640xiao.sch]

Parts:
D1, D2, D3, D4, D5, D6, D7, D8, D9, D10, D11, D12, D13, D14, D15, D16, D17, D18, D19, D20, D21, D22: DIODE; D3_TH_SMD
D1000, D1001, D1002, D1003, D1004: D; D3_TH_SMD
J1, J2: MJ-4PP-9; MJ-4PP-9_1side
J3, J4: MJ-4PP-9; TRSpad
SW1, SW2, SW3, SW4, SW5, SW6, SW7, SW8, SW9, SW10, SW11, SW12, SW13, SW14, SW15, SW16, SW17, SW18, SW19, SW20: SW_PUSH; CherryMX_MidHeight_Choc_Hotswap_katagawa
SW21, SW22: Rotary_Encoder_Switch; RotaryEncoder_Alps_EC12E-Switch_Vertical_H20mm_CircularMoun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
U1: SeeeduinoXIAO; XIAO_RP2040

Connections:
GND: J1.C, J2.C, J3.C, J4.C, SW21.C, SW22.C, U1.13 (GND)
unnamed: D1.1 (K), SW1.2
unnamed: D2.1 (K), SW2.2
unnamed: D3.1 (K), SW3.2
unnamed: D4.1 (K), SW4.2
unnamed: D5.1 (K), SW5.2
unnamed: D6.1 (K), SW6.2
unnamed: D7.1 (K), SW7.2
unnamed: D8.1 (K), SW8.2
unnamed: D9.1 (K), SW9.2
unnamed: D10.1 (K), SW10.2
unnamed: D11.1 (K), SW11.2
unnamed: D12.1 (K), SW12.2
unnamed: D13.1 (K), SW13.2
unnamed: D14.1 (K), SW14.2
unnamed: D15.1 (K), SW15.2
unnamed: D16.1 (K), SW16.2
unnamed: D17.1 (K), SW17.2
unnamed: D18.1 (K), SW18.2
unnamed: D19.1 (K), SW19.2
unnamed: D20.1 (K), SW20.2
unnamed: D21.1 (K), SW21.S2
unnamed: D22.1 (K), SW22.S2
unnamed: D1000.2 (A), SW6.1, SW11.1, SW16.1, SW21.S1
unnamed: D1001.2 (A), SW1.1, SW12.1, SW17.1, SW22.S1
unnamed: D1002.2 (A), SW2.1, SW7.1, SW18.1
unnamed: D1003.2 (A), SW3.1, SW8.1, SW13.1
unnamed: D1004.1 (K), SW4.1, SW9.1, SW14.1, SW19.1
VCC: J1.D, J2.D, J3.D, J4.D, U1.14 (5V)
col0: D1.2 (A), D2.2 (A), D3.2 (A), D4.2 (A), D5.2 (A), D1000.1 (K), U1.4 (PA11_A3_D3)
col1: D6.2 (A), D7.2 (A), D8.2 (A), D9.2 (A), D10.2 (A), D1001.1 (K), U1.5 (PA8_A4_D4_SDA)
col2: D11.2 (A), D12.2 (A), D13.2 (A), D14.2 (A), D15.2 (A), D1002.1 (K), U1.6 (PA9_A5_D5_SCL)
col3: D16.2 (A), D17.2 (A), D18.2 (A), D19.2 (A), D20.2 (A), D1003.1 (K), U1.7 (PB08_A6_D6_TX)
col4: D21.2 (A), D22.2 (A), D1004.2 (A), U1.8 (PB09_A7_D7_RX)
col5: SW5.1, SW10.1, SW15.1, SW20.1, U1.9 (PA7_A8_D8_SCK)
data: J1.B, J2.B, J3.B, J4.B, U1.1 (PA02_A0_D0)
re1a: SW21.A, U1.2 (PA4_A1_D1)
re1b: SW21.B, U1.3 (PA10_A2_D2)
re2a: SW22.A, U1.11 (PA6_A10_D10_MOSI)
re2b: SW22.B, U1.10 (PA5_A9_D9_MISO)

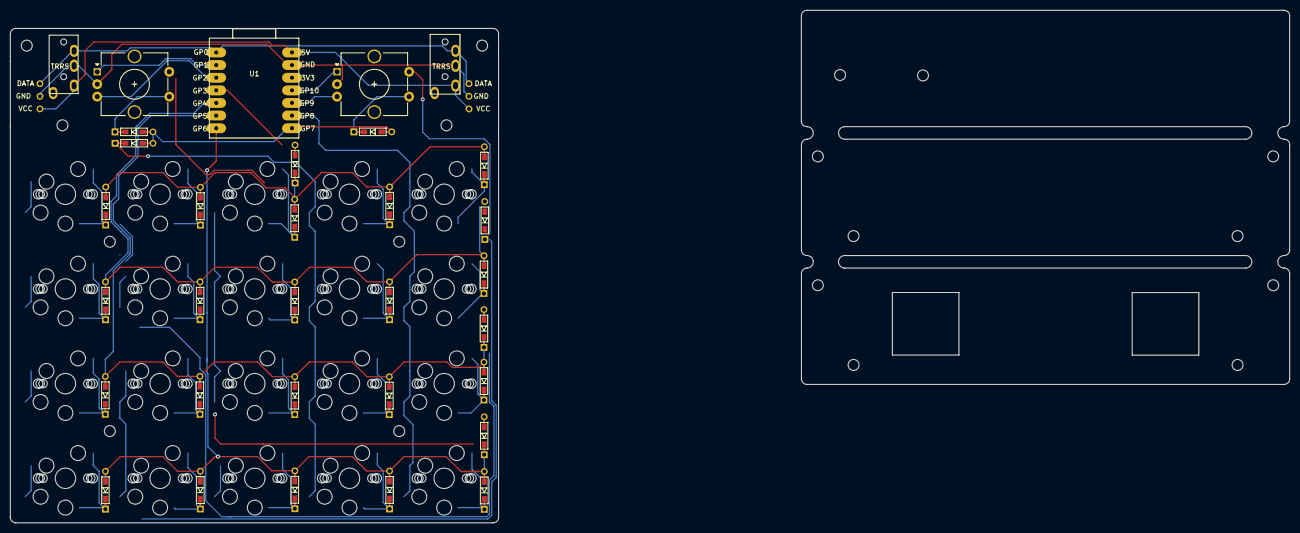
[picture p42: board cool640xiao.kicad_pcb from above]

Board: 2 copper layers, 98.2 x 99.5 mm, 54 parts (0 on the bottom side), 40 nets.

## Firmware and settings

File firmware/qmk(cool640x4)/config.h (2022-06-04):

// Copyright 2022 m.ki (@telzo2000)
// SPDX-License-Identifier: GPL-2.0-or-later

#pragma once

#include "config_common.h"

/* USB Device descriptor parameter */
#define VENDOR_ID    0x4D43
#define PRODUCT_ID   0x0644
#define DEVICE_VER   0x0001
#define MANUFACTURER telzo2000
#define PRODUCT      cool640x4

/* key matrix size */
#define MATRIX_ROWS 18
#define MATRIX_COLS 9

/*
 * Keyboard Matrix Assignments
 *
 * Change this to how you wired your keyboard
 * COLS: AVR pins used for columns, left to right
 * ROWS: AVR pins used for rows, top to bottom
 * DIODE_DIRECTION: COL2ROW = COL = Anode (+), ROW = Cathode (-, marked on diode)
 *                  ROW2COL = ROW = Anode (+), COL = Cathode (-, marked on diode)
 *
 */
#define MATRIX_ROW_PINS { B5, B4, B1, F7, F5, F6, B3, B6, B2 }
#define MATRIX_COL_PINS { B5, B4, B1, F7, F5, F6, B3, B6, B2  }
#define UNUSED_PINS

/* COL2ROW, ROW2COL */
#define DIODE_DIRECTION COL2ROW
#define BOOTMAGIC_LITE_ROW 0
#define BOOTMAGIC_LITE_COLUMN 2


/*
 * Split Keyboard specific options, make sure you have 'SPLIT_KEYBOARD = yes' in your rules.mk, and define SOFT_SERIAL_PIN.
 */
//#define SOFT_SERIAL_PIN D2  // or D1, D2, D3, E6

//#define LED_NUM_LOCK_PIN B0
//#define LED_CAPS_LOCK_PIN B1
//#define LED_SCROLL_LOCK_PIN B2
//#define LED_COMPOSE_PIN B3
//#define LED_KANA_PIN B4

//#define BACKLIGHT_PIN B7
//#define BACKLIGHT_LEVELS 3
//#define BACKLIGHT_BREATHING

#define RGB_DI_PIN D3
#ifdef RGB_DI_PIN
#    define RGBLED_NUM 16
#    define RGBLIGHT_HUE_STEP 8
#    define RGBLIGHT_SAT_STEP 8
#    define RGBLIGHT_VAL_STEP 8
#    define RGBLIGHT_LIMIT_VAL 255 /* The maximum brightness level */
#    define RGBLIGHT_SLEEP  /* If defined, the RGB lighting will be switched off when the host goes to sleep */
/*== all animations enable ==*/
#    define RGBLIGHT_ANIMATIONS
/*== or choose animations ==*/
#    define RGBLIGHT_EFFECT_BREATHING
#    define RGBLIGHT_EFFECT_RAINBOW_MOOD
#    define RGBLIGHT_EFFECT_RAINBOW_SWIRL
#    define RGBLIGHT_EFFECT_SNAKE
#    define RGBLIGHT_EFFECT_KNIGHT
#    define RGBLIGHT_EFFECT_CHRISTMAS
#    define RGBLIGHT_EFFECT_STATIC_GRADIENT
#    define RGBLIGHT_EFFECT_RGB_TEST
#    define RGBLIGHT_EFFECT_ALTERNATING
/*== customize breathing effect ==*/
/*==== (DEFAULT) use fixed table instead of exp() and sin() ====*/
#    define RGBLIGHT_BREATHE_TABLE_SIZE 256      // 256(default) or 128 or 64
/*==== use exp() and sin() ====*/
#    define RGBLIGHT_EFFECT_BREATHE_CENTER 1.85  // 1 to 2.7
#    define RGBLIGHT_EFFECT_BREATHE_MAX    255   // 0 to 255
#endif

/* Debounce reduces chatter (unintended double-presses) - set 0 if debouncing is not needed */
#define DEBOUNCE 5

/* define if matrix has ghost (lacks anti-ghosting diodes) */
//#define MATRIX_HAS_GHOST

/* Mechanical locking support. Use KC_LCAP, KC_LNUM or KC_LSCR instead in keymap */
#define LOCKING_SUPPORT_ENABLE
/* Locking resynchronize hack */
#define LOCKING_RESYNC_ENABLE

/* If defined, GRAVE_ESC will always act as ESC when CTRL is held.
 * This is useful for the Windows task manager shortcut (ctrl+shift+esc).
 */
//#define GRAVE_ESC_CTRL_OVERRIDE

/*
 * Force NKRO
 *
 * Force NKRO (nKey Rollover) to be enabled by default, regardless of the saved
 * state in the bootmagic EEPROM settings. (Note that NKRO must be enabled in the
 * makefile for this to work.)
 *
 * If forced on, NKRO can be disabled via magic key (default = LShift+RShift+N)
 * until the next keyboard reset.
 *
 * NKRO may prevent your keystrokes from being detected in the BIOS, but it is
 * fully operational during normal computer usage.
 *
 * For a less heavy-handed approach, enable NKRO via magic key (LShift+RShift+N)
 * or via bootmagic (hold SPACE+N while plugging in the keyboard). Once set by
 * bootmagic, NKRO mode will always be enabled until it is toggled again during a
 * power-up.
 *
 */
//#define FORCE_NKRO

/*
 * Feature disable options
 *  These options are also useful to firmware size reduction.
 */

/* disable debug print */
//#define NO_DEBUG

/* disable print */
//#define NO_PRINT

/* disable action features */
//#define NO_ACTION_LAYER
//#define NO_ACTION_TAPPING
//#define NO_ACTION_ONESHOT

/* disable these deprecated features by default */
#define NO_ACTION_MACRO
#define NO_ACTION_FUNCTION

/* Bootmagic Lite key configuration */
//#define BOOTMAGIC_LITE_ROW 0
//#define BOOTMAGIC_LITE_COLUMN 0
